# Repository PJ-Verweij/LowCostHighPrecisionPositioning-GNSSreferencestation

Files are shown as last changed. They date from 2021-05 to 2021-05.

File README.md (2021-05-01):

# LowCostHighPrecisionPositioning - GNSSreferencestation

This Github repository contains the manual and production files for the GNSSreferencestation. This design is an improved version of BASE2: [ROVER2 and BASE2 githubpage](https://github.com/PJ-Verweij/LowCostHighPrecisionPositioning---BASE2-ROVER2) <br/><br/>

-In the Documentation folder a manual can be found which explains how to assemble the GNSS reference station <br/>
-In the production files folder the STL file of the antenna top can be found to print the antenna top.
Furthermore, there are Gerber files of the PCB. It is handy to notice that some production facilities also accept the Kicad files. <br/><br/>

-The CAD_model folder can be downloaded an opened with Solidworks (2019 or higher) <br/>
-The PCB folder can be downloaded and opened with KiCad <br/><br/>

-In the Software manuals folder some scripts and instructions are given to demonstrate the functionality of the circuits on the PCB.
For the full Raspberry PI software image and configuration I refer to Andreas Krietemeyer.

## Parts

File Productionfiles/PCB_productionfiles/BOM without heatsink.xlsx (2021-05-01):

Designator | Value | Clarification | Manufacturer | Manufacturer Part Number | Type | Quantity
BT1-BT16 | Battery_Cell | 20700 battery clips | Keystone | 246TR | Thru-Hole | 16
C1-C7 | 10µ | 10µF capacitor | AVX | 12105C106MAT4A | SMD | 7
C8, C9, C14 | 1µ | 1µF capacitor | AVX | 08055C105K4T4A | SMD | 3
C10 | 2.2µ | 2.2µF capacitor | AVX | 12105C225KAZ2A | SMD | 1
C11, C13 | 0.1µ | 0.1µF capacitor | AVX | 08055C104KAT4A | SMD | 2
C12 | 22p | 22pF capacitor | AVX | 06035C220JAT2A | SMD | 1
C15, C18-C20 | 0.1µF | SMD 0.1µF capacitor | AVX | 06035L104K4T4A | SMD | 4
C16 | 10µF | 10µF | AVX | 06033D106MAT2A | SMD | 1
C17 | 22µF | 22µF | AVX | 12063D226KAT2A | SMD | 1
C21 | 22pF | SMD 22pF capacitor | AVX | 06035A220JAT4A | SMD | 1
C22, C25 | 33pF | SMD 33pF capacitor | AVX | 0603YA330F4T2A | SMD | 2
C23 | 100µF | SMD 100µF polarized capacitor | AVX | TCJD107M025R0070E | SMD | 1
C24 | 10pF | SMD 10pF capacitor | AVX | 06035C100K4T4A | SMD | 1
D4, D5 | SMA6T28CAY | ESD protection schottkey diode | STMicroelectronics | SMA6T30CAY | SMD | 2
D1-D3, D6, D10, D11 | LED | SMD RED 2mA LED | Kingbright | APHD1608LSURCK | SMD | 6
D8 | BAT54C | Schottkey diode | Vishay | BAT54C | SMD | 1
D9 | SMA6T30CAY | ESD protection schottkey diode | STMicroelectronics | SMA6T30CAY | SMD | 1
D12, D13 | MBRA210LT3G | Schottkey diode | ON Semiconductor | MBRA210LT3G | SMD | 2
F1 | 8A | 20x5 Fuse holder | Schurter | 318201 | Thru-Hole | 1
F2-F9 | 2A | 20x5 Fuse holder | Schurter | 318201 | Thru-Hole | 8
IC1 | BQ24650RVAT | MPPT solar power converter IC | Texas Instruments | BQ24650RVAT | SMD | 1
IC2 | SC16IS752IPW,128 | I2C to UART IC | NXP | SC16IS752IPW,128 | SMD | 1
J1, J2 | Conn_01x05_Female |  | TE Connectivity / AMP | 4DB-P107-05 | Thru-Hole | 2
J3, J7 | Female Header 1x8 pin |  | Sullins Connector Solutions | PPPC081LFBN-RC | Thru-Hole | 2
J4, J10, J12 | Female Header 1x6 pin |  | Sullins Connector Solutions | PPPC061LFBN-RC | Thru-Hole | 3
J5 | RPi_header |  | Sullins Connector Solutions | PPPC202LFBN-RC | Thru-Hole | 1
J6 | Female Header 1x10 pin |  | Sullins Connector Solutions | PPPC101LFBN-RC | Thru-Hole | 1
J8, J9 | Female Header 1x10 pin (2mm spacing) |  | Sullins Connector Solutions | S5751-10-ND | Thru-Hole | 2
J11 | Conn_Coaxial | Vertical SMA connector | Linx Technologies | CONSMA001-C-G | Thru-Hole | 1
J13 | Conn_Coaxial | U.FL connector | Hirose Connector | U.FL-R-SMT(10) | SMD | 1
JP1 | Jumper_NC_Dual | 1x3 pin header | Amphenol FCI | 10129378-903001BLF | Thru-Hole | 1
L1 | 15µH | 15µH inductor | Coilcraft | SER1390-153MLB | SMD | 1
L2 | MSD1514-252MED | 2.5 µH Coupled-inductor | Coilcraft | MSD1514-252MED | SMD | 1
L3 | 2.2µH | 2.2µH inductor | Coilcraft | D03316P-222 | SMD | 1
L4 | 2.2µH | 2.2µH Coupled-inductor | Bourns | SRF0703-2R2M | SMD | 1
PS1 | LTC3426 | Switching Voltage Regulator | Linear Technology | LTC3426ES6#TRMPBF | SMD | 1
Q3, Q4 | CSD16406Q3 | N-Channel mosfet | Texas Instruments | CSD16406Q3 | SMD | 2
Q5 | DTC143Z | Bipolar transistor pre biased | Nexperia | NHDTC143ZTR | SMD | 1
R1 | 560 | SMD 560Ohm resistor | Vishay | CRCW0603560RFKEAC | SMD | 1
R2-R5 | 1.5K | SMD 1.5K resistor | Vishay | CRCW06031K50FKEAC | SMD | 4
R6 | 0.008 | SMD 0.008Ω current sense resistor | Vishay/Dale | WSLP25128L000FEA | SMD | 1
R7 | 10 | SMD 10Ω resistor | Vishay / Dale | RCS120610R0FKEA | SMD | 1
R8 | 324K | SMD 324K resistor | Vishay / Dale | CRCW0603324KFKEA | SMD | 1
R9 | 511K | SMD 511K resistor | Vishay / Dale | CRCW0603511KFKEA | SMD | 1
R10 | 2 | SMD 2Ω resistor | Vishay / Dale | CRCW08052R00FKEAC | SMD | 1
R11 | 36K | SMD 36K resistor | Vishay / Dale | CRCW060336K0FKEAC | SMD | 1
R12 | 340K | SMD 340K resistor | Vishay/Dale | CRCW0603340KFKEAC | SMD | 1
R13 | 348K | SMD 348K resistor | Vishay/Dale | CRCW0603348KFKEA | SMD | 1
R14, R16 | 820 | SMD 820Ω resistor | Vishay / Dale | CRCW0603820RFKEA | SMD | 2
R15 | 3.48K | SMD 3.48K resistor | Vishay / Dale | CRCW06033K48FKEA | SMD | 1
R17 | 14.7K | SMD 14.7K resistor | Vishay / Dale | CRCW060314K7FKEB | SMD | 1
R18 | 330 | SMD 330ohm resistor | Vishay | CRCW0603330RFKEA | SMD | 1
R19 | 2.2K | SMD 2.2K resistor | Vishay | CRCW06032K20JNEA | SMD | 1
R20, R21 | 5.1M | SMD 5.1M resistor | Vishay | CRCW06035M10FKEA | SMD | 2
R22 | 95.3K | SMD 95.3K resistor | Vishay | CRCW060395K3FKEA | SMD | 1
R23 | 1M | SMD 1M resistor | Vishay | CRCW06031M00FKEB | SMD | 1
R24 | 30.9K | SMD 30.9K resistor | Vishay | CRCW060330K9FKEA | SMD | 1
R25 | 10K | SMD 10K resistor | Vishay | CRCW060310K0FKEAC | SMD | 1
R26, R27 | 1K | SMD 1K resistor | Vishay | CRCW06031K00FKEAC | SMD | 2
TH1 | 10K | 10K NTC Thermistor | Semitec | 103AT-2 | Thru-Hole | 1
U1 | BQ29700 | Battery protection circuit | Texas Instruments | BQ29700DSER | SMD | 1
U2 | LM35-LP | Temperature sensor | Texas Instruments | LM35DZ | Thru-Hole | 1
U3 | MCP3008 | MCP3008 analog-digital converter | Microchip | MCP3008T-I/SL | SMD | 1
Y1 | 14.7456M | 14.7456Mhz crystal | IQD | LFXTAL003224 | Thru-Hole | 1

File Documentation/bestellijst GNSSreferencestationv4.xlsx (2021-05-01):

Component | Single piece price | Package | Amount 1 unit | 1 Unit | Amount 10 units | 10 units price | Amount 20 units | 20 units price | Discount percentage for 20 units
Enclosure FLT 350250150 GR | €22.32 | 1 | 1 | €22.3 | 10 | €223.2 | 20 | €433.01 | 3% | https://www.reichelt.nl/nl/nl/wandgehaeuse-ip65-250-x-350-x-150-mm-grau-flt-350250150-gr-p262988.html?nbc=1
GSM antenna DELOCK 89618 | €7.52 | 1 | 1 | €7.5 | 10 | €75.2 | 20 | €150.40 | 0% | https://www.reichelt.de/gb/en/lte-antenna-sma-plug-omnidirectional-delock-89618-p259573.html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
Raspberry Zero | €12.25 | 1 | 1 | €12.2 | 10 | €122.5 | 20 | €245.00 | 0% | https://www.reichelt.nl/nl/nl/raspberry-pi-zero-v-1-3-1-ghz-512-mb-ram-rasp-pi-zero-p256439.html?nbc=1
 |  |  | Shop sum: | €42.1 |  | €420.9 |  | €828.41
Cell 21700 Samsung INR21700-50E | €6.45 | 1 | 8 | €63.7 | 80 | €461.6 | 160 | €923.20 | 27.51256281% | https://www.tme.eu/nl/details/accu-inr21700-50e/accus/samsung-sdi/inr21700-50e/
NAC3MPX-TOP NEUTRIK | €3.82 | 1 | 1 | €3.8 | 10 | €33.9 | 20 | €67.8 | 11.2565445% | https://www.tme.eu/nl/details/ntr-nac3mpx-top/overige-ac-connectoren/neutrik/nac3mpx-top/
NAC3FX-W-TOP NEURTIK | €9.06 | 1 | 1 | €9.1 | 10 | €81.5 | 20 | €145.0 | 19.97792494% | https://www.tme.eu/nl/details/ntr-nac3fx-w-top/overige-ac-connectoren/neutrik/nac3fx-w-top/
SCNAC-MPX NEUTRIK | €1.26 | 1 | 1 | €1.3 | 10 | €11.3 | 20 | €20.2 | 19.84126984% | https://www.tme.eu/nl/details/ntr-scnac-mpx/overige-connectors-van-neutrik/neutrik/scnac-mpx/
spacer m2.5x10mm | €0.13 | 1 | 7 | €0.9 | 70 | €9.2 | 140 | €15.1 | 17.41787624% | https://www.tme.eu/nl/details/tfm-m2.5x10_dr2112/metalen-afstandhouders/dremec/2112x10/
m2.5 nut (steel) | €0.88 | 100 | 7 | €0.1 | 70 | €0.6 | 140 | €1.23 | 0% | https://www.tme.eu/nl/details/b2.5_bn109/moeren/bossard/1088254/
m2.5x6 philipshead bolt (Steel) | €2.30 | 100 | 7 | €0.2 | 70 | €1.6 | 140 | €3.22 | 0% | https://www.tme.eu/nl/details/b2.5x6_bn1435/bouten/bossard/1219561/
spacer m4x10mm | €0.13 | 1 | 7 | €0.9 | 70 | €9.23 | 140 | €15.2 | 17.81652767% | https://www.tme.eu/nl/details/tfm-m4x10_dr226/metalen-afstandhouders/dremec/226x10/
m4 nut (steel) | €1.04 | 100 | 7 | €0.1 | 70 | €0.7 | 140 | €1.46 | 0% | https://www.tme.eu/nl/details/b4_bn115/moeren/bossard/1089013/
m4x6 philipshead bolt (Steel) | €2.02 | 100 | 7 | €0.1 | 70 | €1.4 | 140 | €2.83 | 0% | https://www.tme.eu/nl/details/b4x6_bn1435/bouten/bossard/1219928/
m4x25 sockethead bolt (RVS) | €2.87 | 100 | 2 | €0.1 | 20 | €0.6 | 40 | €1.15 | 0% | https://www.tme.eu/nl/details/m4x25_d912-a2/bouten/kraftberg/
m4 nut (RVS) | €0.72 | 100 | 2 | €0.0144 | 20 | €0.1 | 40 | €0.29 | 0% | https://www.tme.eu/nl/details/m4_d934-a2/moeren/kraftberg/
m8x40 sockethead bolt (RVS) | €12.74 | 100 | 1 | €0.1 | 10 | €1.3 | 20 | €2.55 | 0% | https://www.tme.eu/nl/details/m8x40_d912-a2/bouten/kraftberg/
m8 nut (RVS) | €3.12 | 100 | 1 | €0.03 | 10 | €0.3 | 20 | €0.62 | 0% | https://www.tme.eu/nl/details/m8_d934-a2/moeren/kraftberg/
m3x8 sockethead bolt (Steel) | €3.10 | 100 | 2 | €0.06 | 20 | €0.6 | 40 | €1.24 | 0% | https://www.tme.eu/nl/details/b3x8_bn17/bouten/bossard/3186761/
m3 nut (Steel) | €0.95 | 100 | 2 | €0.02 | 20 | €0.2 | 40 | €0.38 | 0% | https://www.tme.eu/nl/details/b3_bn115/moeren/bossard/1088998/
16GB SD card Sandisk | €5.60 | 1 | 1 | €5.6 | 10 | €50.1 | 20 | €88.6 | 20.89285714% | https://www.tme.eu/nl/details/sdsquns-016g-gn3mn/geheugenkaarten/sandisk/
Stego | €11.16 | 1 | 1 | €11.2 | 10 | €99.60 | 20 | €176.60 | 20.8781362% | https://www.tme.eu/nl/details/08410.0-00/cabinets-accessories/stego/
PG9 cable gland | €1.80 | 5 | 2 | €0.7 | 20 | €7.20 | 40 | €14.40 | 0% | https://www.tme.eu/nl/details/pg9_bk/wartels/aks-zielonka/220215/
2x20pin header for raspberry | €3.29 | 10 | 1 | €0.3 | 10 | €3.29 | 20 | €6.58 | 0% | https://www.tme.eu/nl/details/zl202-40g/lijsten-en-pin-achtige-stopcontacten/connfly/ds1021-2-20sf11/
1x20pin header for GNSS receiver | €1.96 | 10 | 2 | €0.4 | 20 | €3.92 | 50 | €7.77 | 0.8928571429% | https://www.tme.eu/nl/details/zl201-20g/lijsten-en-pin-achtige-stopcontacten/connfly/ds1021-1-20sf11/
Fuses 2A | €1.17 | 10 | 8 | €0.9 | 80 | €8.2 | 160 | €12.78 | 31.70940171% | https://www.tme.eu/nl/details/zcs-2a/zekeringen-5x20mm-snele/eska/520-520/
Fuses 8A | €1.04 | 10 | 1 | €0.1 | 10 | €1.0 | 20 | €2.08 | 0% | https://www.tme.eu/nl/details/zks-8a_125v/zekeringen-5x20mm-snele/eska/520-626/
M4 cable lug | €0.70 | 10 | 6 | €0.4 | 60 | €3.2 | 120 | €6.43 | 22.99956903% | https://www.tme.eu/nl/details/tmev1.25-4m/geisoleerde-connectoren/nichifu/tmev-1-25-4m/
Cable black 18AWG | €21.27 | 30 | 1 | €0.7 | 10 | €7.1 | 20 | €14.18 | 0% | https://www.tme.eu/nl/details/1555-bk005/enkeladerige-draden-koord/alpha-wire/1555-bk005/
Cable red 18AWG | €21.27 | 30 | 1 | €0.7 | 10 | €7.1 | 20 | €14.18 | 0% | https://www.tme.eu/nl/details/1555-rd005/enkeladerige-draden-koord/alpha-wire/1555-rd005/
Cable 2 wires 17AWG | €3.85 | 5 | 3 | €2.3 | 30 | €20.7 | 60 | €36.60 | 20.77922078% | https://www.tme.eu/nl/details/ol-eb-2x1/meeraderige-draden-niet-afgeschermd/lapp/0012440/
Jumper | €0.66 | 20 | 1 | €0.03 | 10 | €0.3 | 20 | €0.66 | 0% | https://www.tme.eu/nl/details/jumper-r-z/lijsten-en-pin-achtige-stopcontacten/ninigi/
 |  |  | Shop sum: | €99.6 |  | €787.5 |  | €1510.29
ON/OFF switch | €4.91 | 1 | 1 | €4.91 | 10 | €49.10 | 20 | €98.20 | 0% | https://nl.rs-online.com/web/p/push-button-switches/7064073/?searchHistory=%7B%22enabled%22%3Atrue%7D
Panel Mount Indicator, 8mm | €4.12 | 1 | 1 | €4.12 | 10 | €37.70 | 20 | €75.40 | 8.495145631% | https://nl.rs-online.com/web/p/indicators/1950260/
 |  |  | Shop sum: | €9.03 |  | €86.80 |  | €173.60
SBR10U40CT | €1.19 | 1 | 1 | €1.19 | 10 | €9.74 | 20 | €19.48 | 18.1512605% | https://nl.mouser.com/ProductDetail/Diodes-Incorporated/SBR10U40CT?qs=7r0W2zb%2F88xvLBVZUVD9Zw%3D%3D
513002B02500G | €0.85 | 1 | 2 | €1.71 | 20 | €16.30 | 40 | €31.64 | 7.485380117% | https://nl.mouser.com/ProductDetail/Aavid/513002B02500G
CSD18537NKCS | €1.15 | 1 | 2 | €2.30 | 20 | €19.14 | 40 | €38.28 | 16.7826087% | https://nl.mouser.com/ProductDetail/Texas-Instruments/CSD18537NKCS
 |  |  | Shop sum: | €5.20 |  | €45.18 |  | €89.40
PCB | €778.70 | 1 | 1 | €778.7 | 10 | €1938.6 | 20 | €2889.80 | 81.44471555% | https://www.eurocircuits.com/
Aluminium 120mmx2mm groundplane | €11.90 | 1 | 1 | €11.9 | 10 | €30.0 | 20 | €43.40 | 81.76470588% | https://www.metalpoint.nl/vlak-plaatwerk/schijf.html
Ardusimple | €211.00 | 1 | 1 | €211.0 | 10 | €2110.0 | 20 | €4220.00 | 0% | https://www.ardusimple.com/product/simplertk2b-basic-starter-kit-ip65/
SPP040201200 (20watt, polycristaline -> panel used in design) | €34.95 | 1 | 1 | €34.95 | 10 | €349.50 | 20 | €699.00 | 0% | https://www.druppellader.com/victron-bluesolar-20wp-poly.html
SPM040201200 (20Watt, monocrystalline) | €37.51 | 1 | 1 | €37.5 | 10 | €375.1 | 20 | €750.20 | 0% | https://www.bluepowershop.nl/solar/solar-panelen/victron-solar-panel-20w-12v-mono.html
SPP040301200 (30Watt, polycrystalline) | €39.95 | 1 | 1 | €40.0 | 10 | €399.5 | 20 | €799.00 | 0% | https://www.acculaders.nl/victron-bluesolar-30wp-poly.html
SPM040301200 (30Watt, monocrystalline) | €43.56 | 1 | 1 | €43.6 | 10 | €435.6 | 20 | €871.20 | 0% | https://www.bluepowershop.nl/solar/solar-panelen/victron-solar-panel-30w-12v-mono.html
SPM040401200 (40Watt, monocrystalline) | €55.66 | 1 | 1 | €55.7 | 10 | €556.6 | 20 | €1113.20 | 0% | https://www.bluepowershop.nl/solar/victron-solar-panel-40w-12v-mono.html
SPM040551200 (50Watt, monocrystalline) | €72.60 | 1 | 1 | €72.6 | 10 | €726.0 | 20 | €1452.00 | 0% | https://www.bluepowershop.nl/solar/solar-panelen/victron-solar-panel-55w-12v-mono.html
3D printed antenna platform (PETG) |  |  |  |  |  |  |  |  |  | Github page
Aluminium pole 25x2x1000 | €6.90 | 1 | 1 | €6.9 | 10 | €69.0 | 20 | €138.00 | 0% | https://www.aluminiumopmaat.nl/aluminium-buizen/aluminium-buis-rond.html
Saddle clamps for pole | €1.94 | 1 | 2 | €3.9 | 20 | €38.8 | 40 | €77.60 | 0% | https://nl.rs-online.com/web/p/cable-clips-clamps/0606018/
 |  |  | Total order sum: | €1192.5 |  | €5768.5 |  | €10453.90
 |  |  | Unit price: | €1192.5 |  | €576.9 |  | €522.69 | (without pole and clamps, with 20watt polycristalline panel)
Normal text = Needed components
Orange text = optional comonents

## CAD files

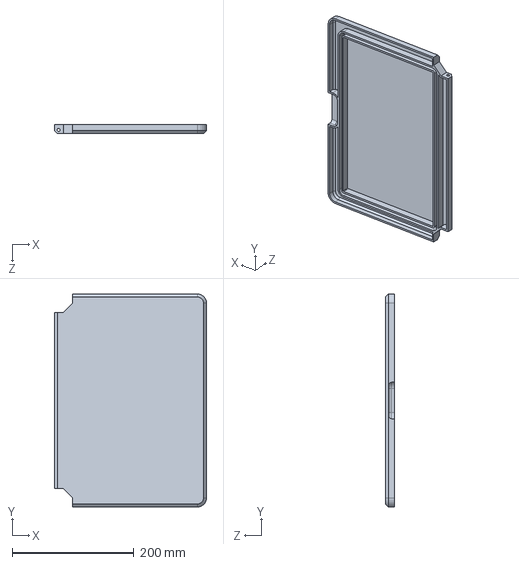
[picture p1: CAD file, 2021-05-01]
CAD_model/Main_unit/Enclosure-components/Main-Unit.Enclosure.Door.SLDPRT
250.0 x 350.0 x 15.0 mm

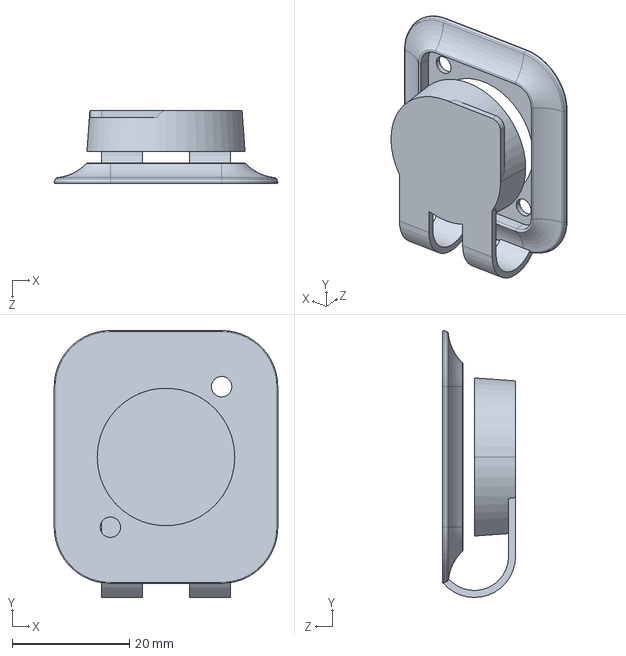
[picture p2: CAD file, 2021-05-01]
CAD_model/Main_unit/Enclosure-components/Neutric_Connector/Main-Unit.Neutric_Connector.3-d-scnac-mpx.SLDPRT
38.2 x 45.6 x 12.5 mm

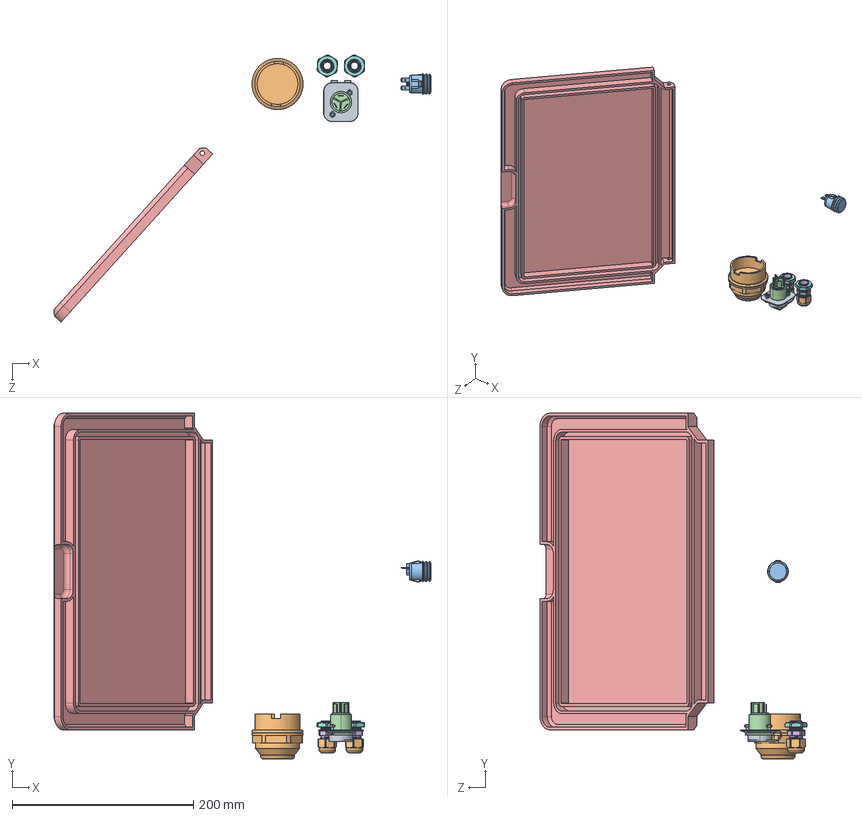
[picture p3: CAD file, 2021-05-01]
CAD_model/Main_unit/Main-Unit.Enclosure.Assembly.SLDASM
416.4 x 382.0 x 295.1 mm
Main-Unit.Enclosure.Door
Cable Gland PG7-PG19 Body x 2
Cable Gland PG7-PG19 Washer x 2
Cable Gland PG7-PG19 Lock Nut x 2
Cable Gland PG7-PG19 Sleeve x 2
Cable Gland PG7-PG19 Gland Nut x 2
Main-Unit.Neutric_Connector.NAC3MPX-TOP
Main-Unit.Button_kfb2ana1bbb
Main-Unit.Drainelement_08410.0-00-STEGO-base
Main-Unit.Neutric_Connector.3-d-scnac-mpx
countersunk flat head cross recess screw_din x 2
hex nut style 1 gradeab_din x 2

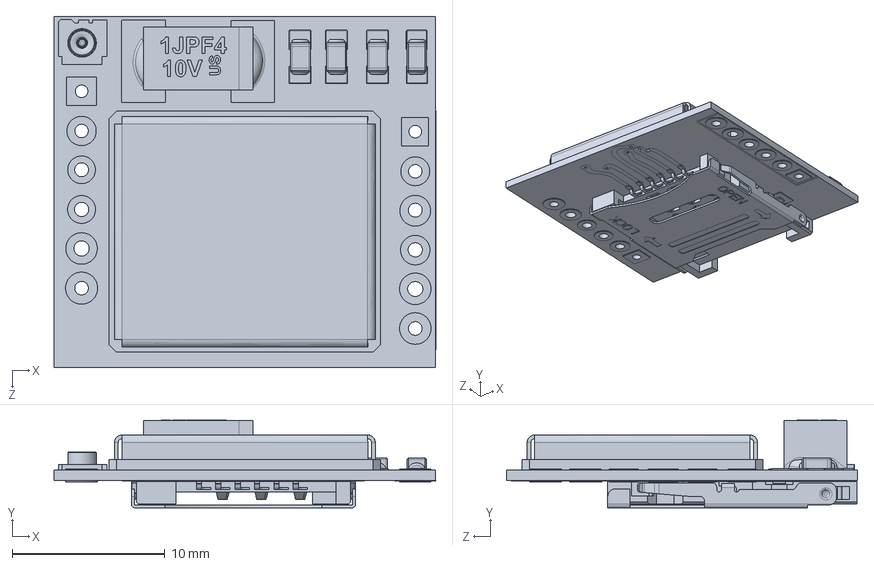
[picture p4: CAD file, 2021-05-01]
CAD_model/Main_unit/PCB-components/Main-Unit.SIM800_GPRSmodem.SLDPRT
25.0 x 5.77 x 23.0 mm

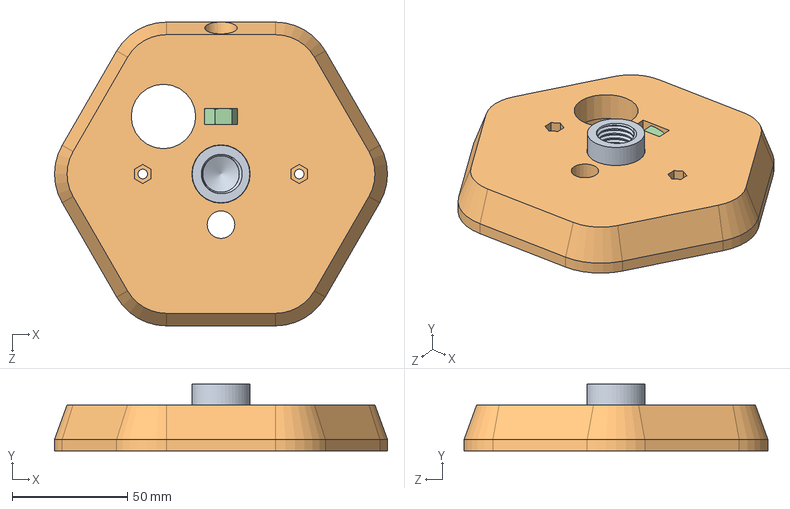
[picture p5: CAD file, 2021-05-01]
CAD_model/Antenna/antennatop58-11uncadapter.SLDASM
144.7 x 29.0 x 132.0 mm
thread adapter antenna top
antenna top
socket head cap screw_am
hex nut style 2_am

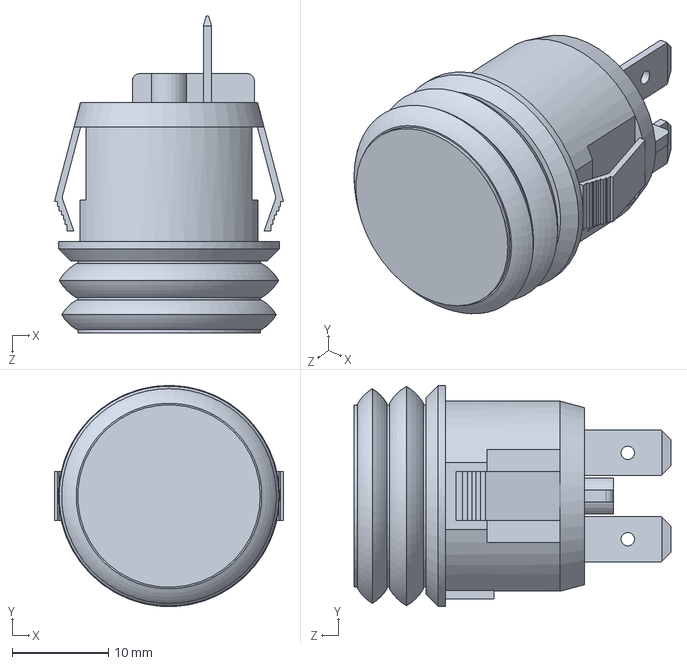
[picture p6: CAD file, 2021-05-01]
CAD_model/Main_unit/Enclosure-components/Main-Unit.Button_kfb2ana1bbb.SLDPRT
23.8 x 23.0 x 33.0 mm

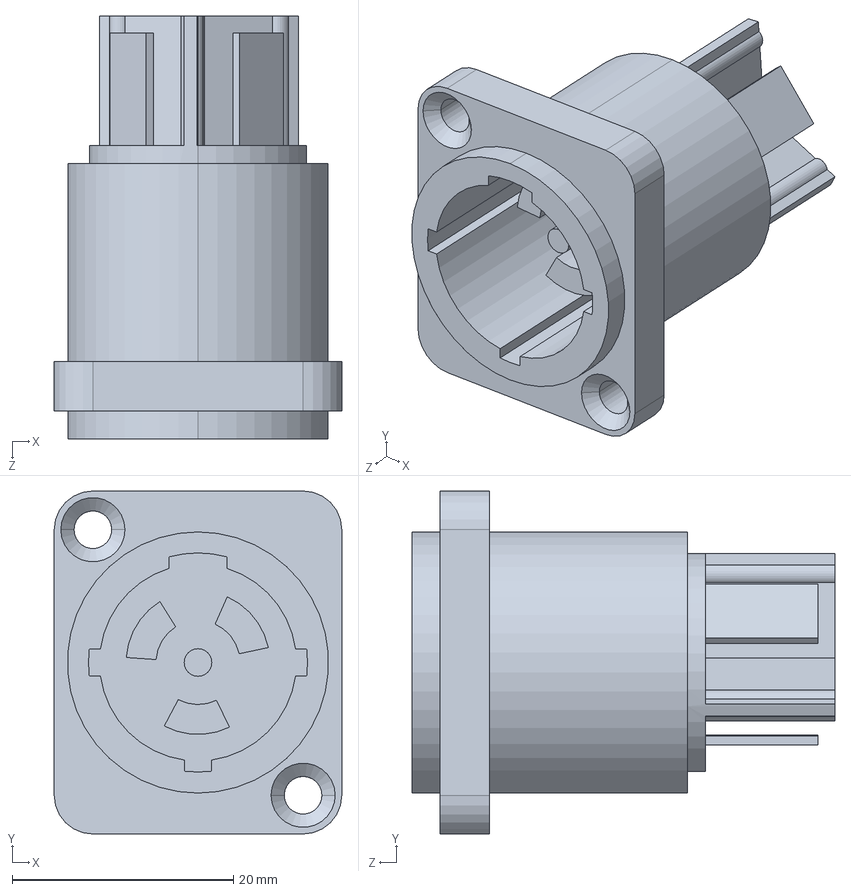
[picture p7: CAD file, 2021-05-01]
CAD_model/Main_unit/Enclosure-components/Neutric_Connector/Main-Unit.Neutric_Connector.NAC3MPX-TOP.SLDPRT
26.0 x 31.0 x 38.2 mm

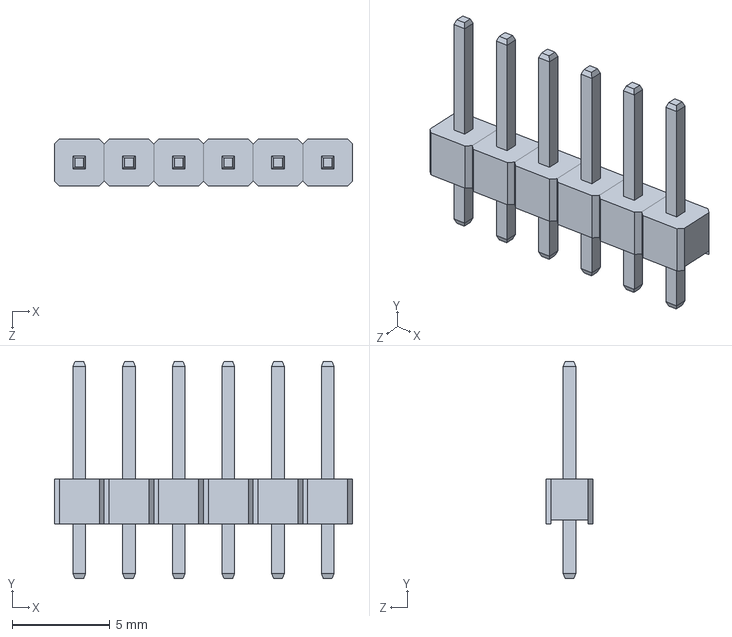
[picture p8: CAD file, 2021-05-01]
CAD_model/Main_unit/PCB-components/Pinheaders/Main-Unit.6x_Pinheader_2.54mm.Assembly.SLDASM
15.2 x 11.1 x 2.40 mm
Main-Unit.Male_Pin_2.54_mm x 6

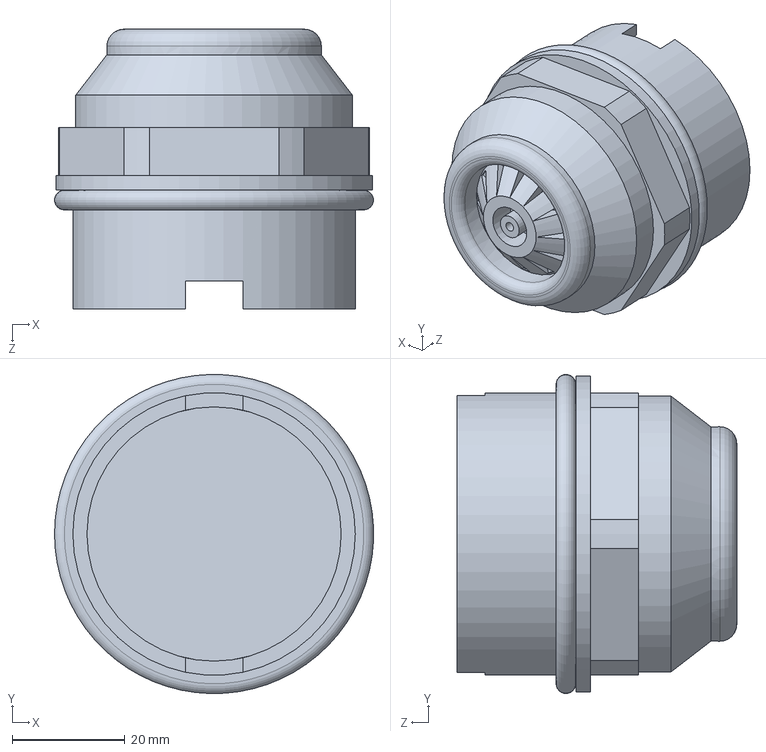
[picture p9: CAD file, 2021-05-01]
CAD_model/Main_unit/Enclosure-components/Main-Unit.Drainelement_08410.0-00-STEGO-base.SLDPRT
56.5 x 56.5 x 49.5 mm

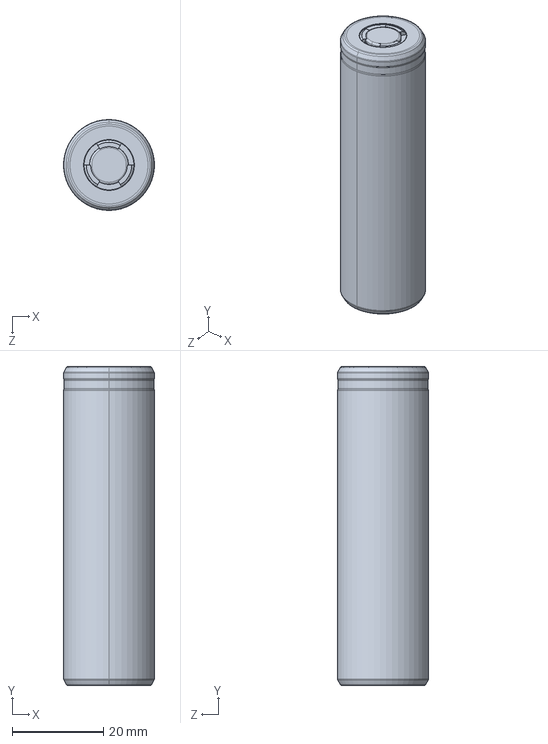
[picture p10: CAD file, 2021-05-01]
CAD_model/Main_unit/PCB-components/Main-Unit.21700_Battery.SLDPRT
19.9 x 70.0 x 20.0 mm

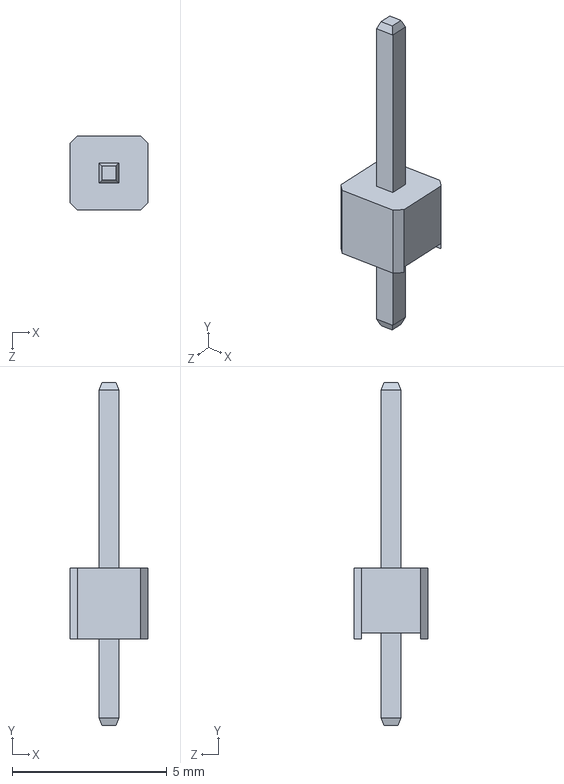
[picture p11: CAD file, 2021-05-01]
CAD_model/Main_unit/PCB-components/Pinheaders/Main-Unit.Male_Pin_2.54_mm.SLDPRT
2.54 x 11.1 x 2.40 mm

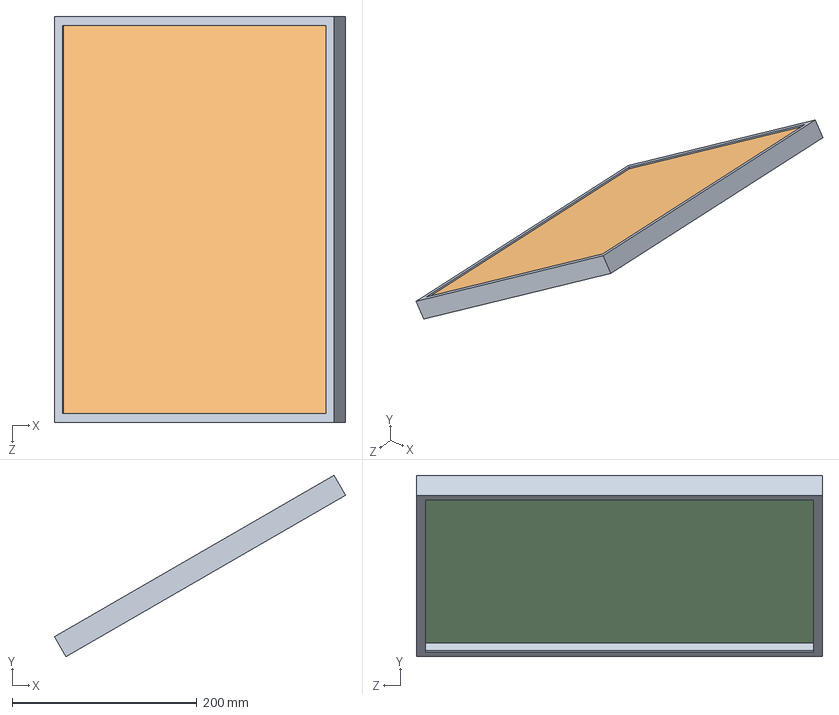
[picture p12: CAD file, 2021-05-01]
CAD_model/Solarpanel/GNSSreferencestation.Solarpanel.Assembly.SLDASM
315.6 x 196.7 x 440.0 mm
Solarpanel.sides
Solarpanel.glass
Solarpanel.cells
Solarpanel.backplate

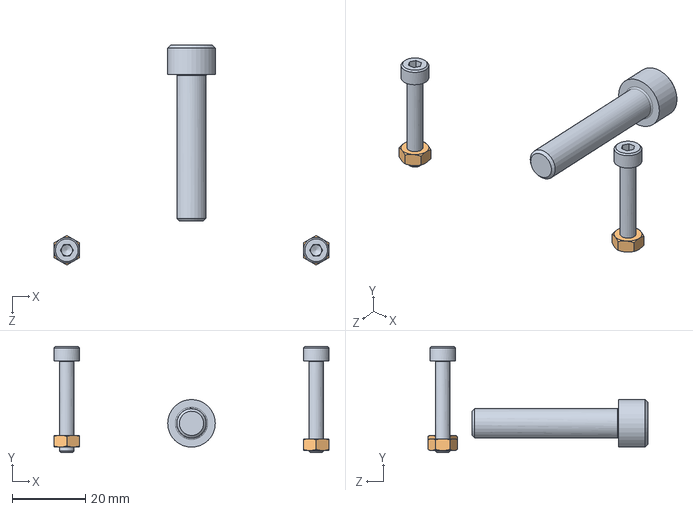
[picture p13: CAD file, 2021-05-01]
CAD_model/Antenna/GNSSreferencestation.Antenna.Assembly.SLDASM
75.0 x 29.0 x 60.0 mm
socket head cap screw_am x 3
hex nut style 1_am x 2

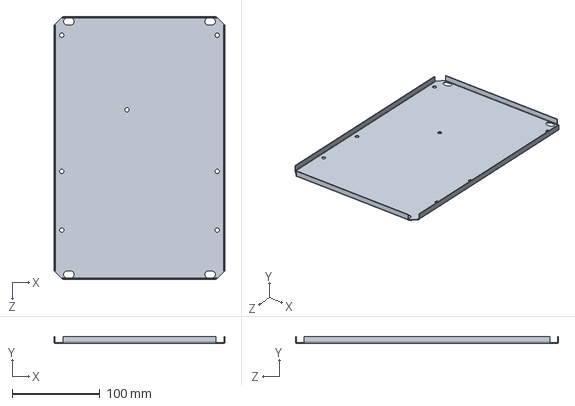
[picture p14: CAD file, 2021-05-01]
CAD_model/Main_unit/Enclosure-components/Main-Unit.Enclosure.Backplate.SLDPRT
195.0 x 8.00 x 300.0 mm

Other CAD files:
CAD_model/Main_unit/PCB-components/Pinheaders/Main-Unit.10x_Pinheader_2mm.sldprt
CAD_model/Main_unit/PCB-components/Main-Unit.Example_Xbee.Assembly.sldasm
CAD_model/Solarpanel/Solarpanel.Victron_20watt.Assembly.SLDASM
CAD_model/Main_unit/PCB-components/Main-Unit.SIM800_GPRSmodem_Withheader.Assembly.SLDASM
CAD_model/Antenna/Antenna.Antennatop.Assembly.SLDASM
CAD_model/Antenna/Antenna.Pole-1000mmx25mm.SLDPRT
CAD_model/Antenna/Antennatop.Base.SLDPRT
CAD_model/Antenna/Antennatop.Cellular-Antenna.SLDPRT
CAD_model/Antenna/Antennatop.Groundplane.SLDPRT
CAD_model/Antenna/thread adapter antenna top.SLDPRT
CAD_model/Antenna/thread adapter.SLDDRW
CAD_model/Main_unit/Cable-gland-pg7-pg19/Cable Gland PG7-PG19 Body.SLDPRT
CAD_model/Main_unit/Cable-gland-pg7-pg19/Cable Gland PG7-PG19 Gland Nut.SLDPRT
CAD_model/Main_unit/Cable-gland-pg7-pg19/Cable Gland PG7-PG19 Lock Nut.SLDPRT
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

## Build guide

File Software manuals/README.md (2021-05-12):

In the subfolders of this directory you can find software manuals to get the separate hardware components to work on a fresh install of raspberry PI OS

However, there is also a pre-configured image for the GNSSreferencestation (still to be uploaded)
This image can be written to the SD card using the DD command or the graphical <a href="https://github.com/thefanclub/dd-utility">DD utility</a>. (available for Mac OS and Linux)

In the image you still have to edit file [fixme] to fill the right [mountpoint] and [telecomprovider data]

Also remember to upload the base station configuration to the GNSS receiver using the Ublox U-center software.

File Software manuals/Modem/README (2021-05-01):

How to get SIM800 to work with Raspberry PI

1. Make internet connection for installation
Connect Raspberry to Internet by Wifi or Ethernet

2. Enable serial port
In Raspberry Pi configuration -> interfaces
- Enable Serial Port
- Disable Serial Console

3. Turn off pincode
This step only has to be done if the SIM card still has an active pincode
Turning of the pincode is needed while the AT+CPIN command reply’s with OK to soon. This will cause the chat script to go on before the modem is ready.

Install minicom
Terminal commands:
sudo apt-get update
sudo apt-get install minicom

Connect to modem
Terminal command:
sudo minicom -D /dev/ttyS0 -b 115200

Turn off pincode in minicom
minicom command:
ATZ should return OK
AT+CPIN? should return +CPIN: SIM PIN indicating SIM PIN is needed
AT+CPIN="xxxx" replace xxxx by your PINCODE. should return OK. you have access to the SIM
AT+CLCK="SC",0,"xxxx" replace xxxx by your PINCODE. to disable the pin code

4. Install ppp, for serial data connections
Terminal commands:
Sudo apt-get update
Sudo apt-get install ppp

5. Place configuration and chatscript
Create or paste the chatscript in folder /etc/ppp (GPRS.chat, can be found in this directory)
Create or paste the ppp configuration file in /etc/ppp/peers (GPRSconfig, can be found in this directory, you might need to alter the APN username and password in this file.)

6. Start the connection
Terminal command:
Sudo pon GPRSconfig
(Connection can be turned off again with “Sudo off GPRSconfig”)

7. Check the connection
Terminal command:
Ifconfig
This will now show a new connection: ppp0
The proces of setting up the connection and potential errors can be tracked with te terminal command:
cat /var/log/syslog | grep pppd

8. Make the ppp0 connection the default route
Terminal command:
Sudo route add default dev ppp0

9. Check the connection
Load a webpage in the browser or ping an webadres with terminal command:
Ping google.com

If you have a browser, speedtest can be run at:
TestMy.net
Upload will be between 30 and 45kbps
Download will be between 80 and 100kbps

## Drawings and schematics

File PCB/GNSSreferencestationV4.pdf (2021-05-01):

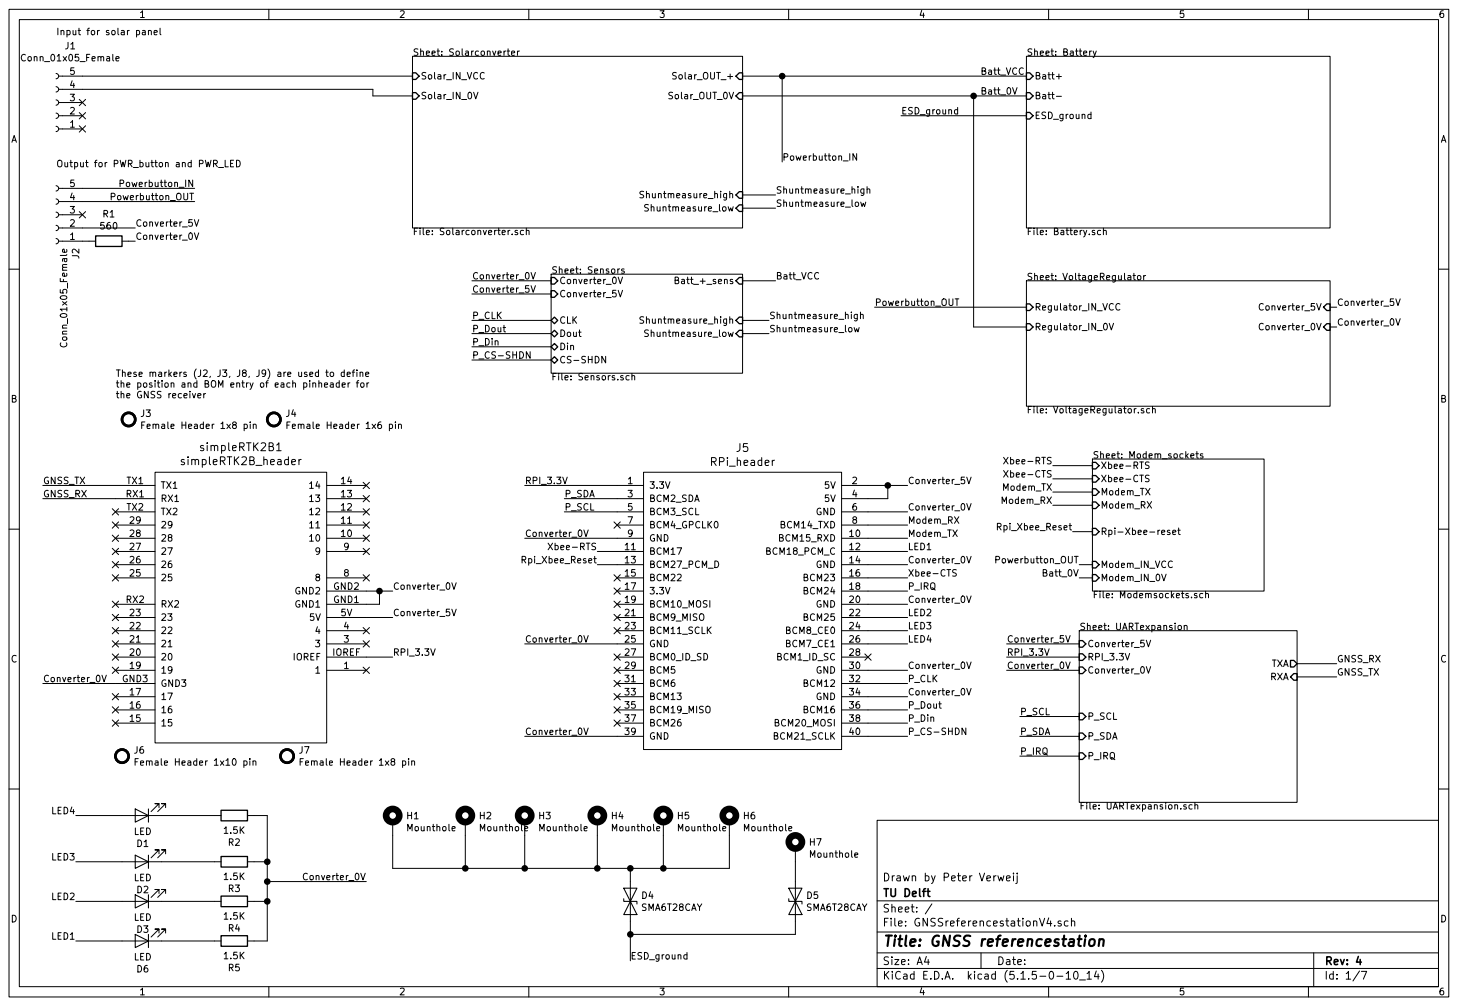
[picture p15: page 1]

Input for solar panel

Sheet: Battery
File: Battery.sch Batt+ Batt- ESD_ground
Batt_0V Converter_0V Converter_0V Converter_0V

the GNSS receiver Output for PWR_button and PWR_LED

Sheet: Sensors File: Sensors.sch Converter_0V Converter_5V CLK Dout Din CS-SHDN

These markers (J2, J3, J8, J9) are used to define
the position and BOM entry of each pinheader for

Sheet: Modem_sockets File: Modemsockets.sch Xbee-RTS

Xbee-CTS Modem_TX Modem_RX Rpi-Xbee-reset Modem_IN_VCC Modem_IN_0V

File: GNSSreferencestationV4.sch Sheet: / TU Delft Drawn by Peter Verweij

Id: 1/7 Title: GNSS referencestation

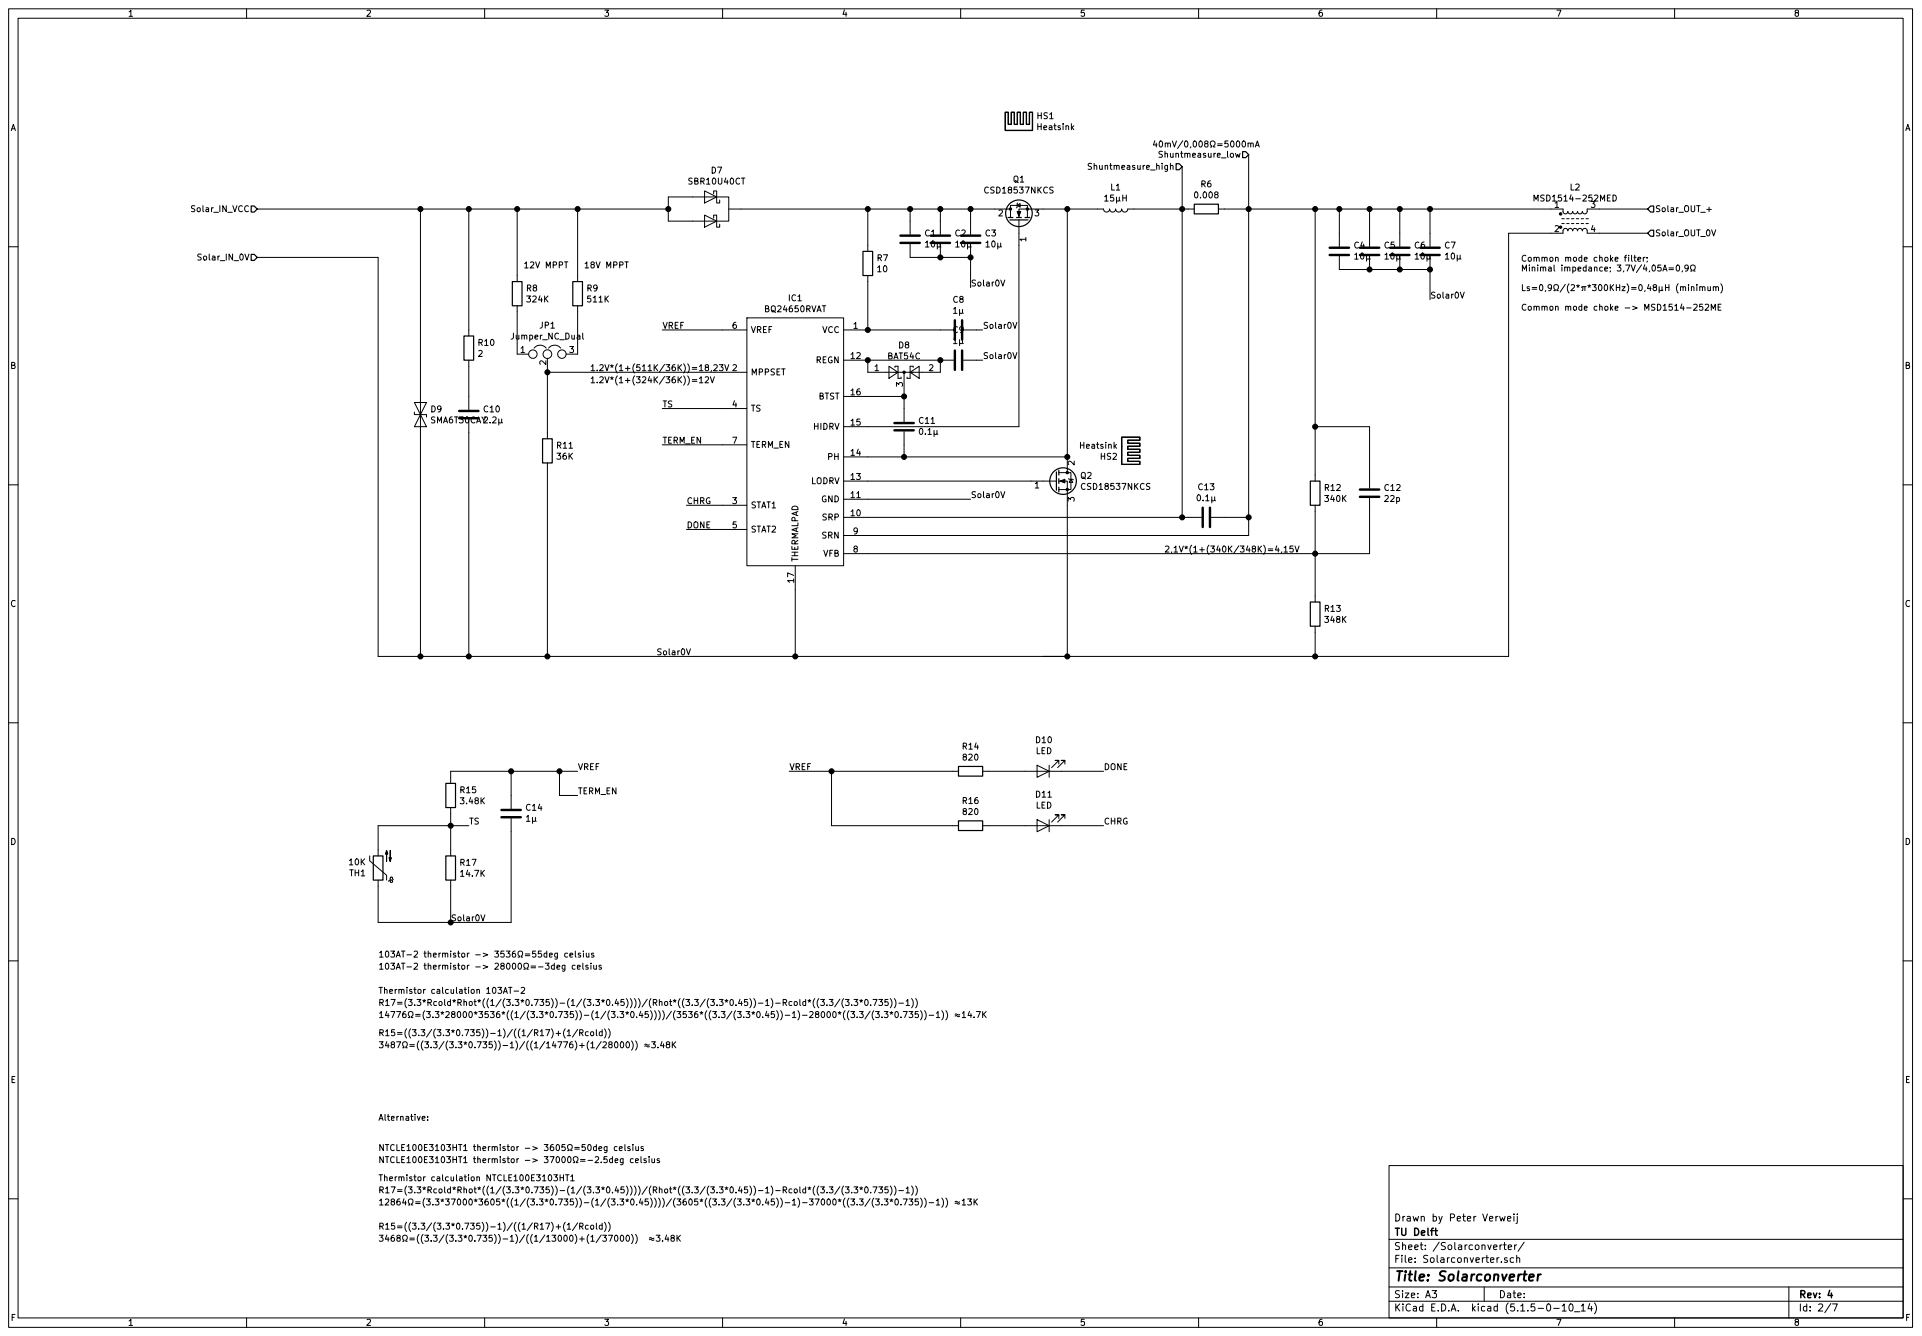
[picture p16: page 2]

Common mode choke filter; Minimal impedance; 3,7V/4,05A=0,9

Ls=0,9/(2**300KHz)=0,48µH (minimum) Common mode choke -> MSD1514-252ME

NTCLE100E3103HT1 thermistor -> 3605=50deg celsius
NTCLE100E3103HT1 thermistor -> 37000=-2.5deg celsius
Thermistor calculation NTCLE100E3103HT1
R17=(3.3*Rcold*Rhot*((1/(3.3*0.735))-(1/(3.3*0.45))))/(Rhot*((3.3/(3.3*0.45))-1)-Rcold*((3.3/(3.3*0.735))-1))

Id: 2/7 Title: Solarconverter File: Solarconverter.sch Sheet: /Solarconverter/ TU Delft Drawn by Peter Verweij

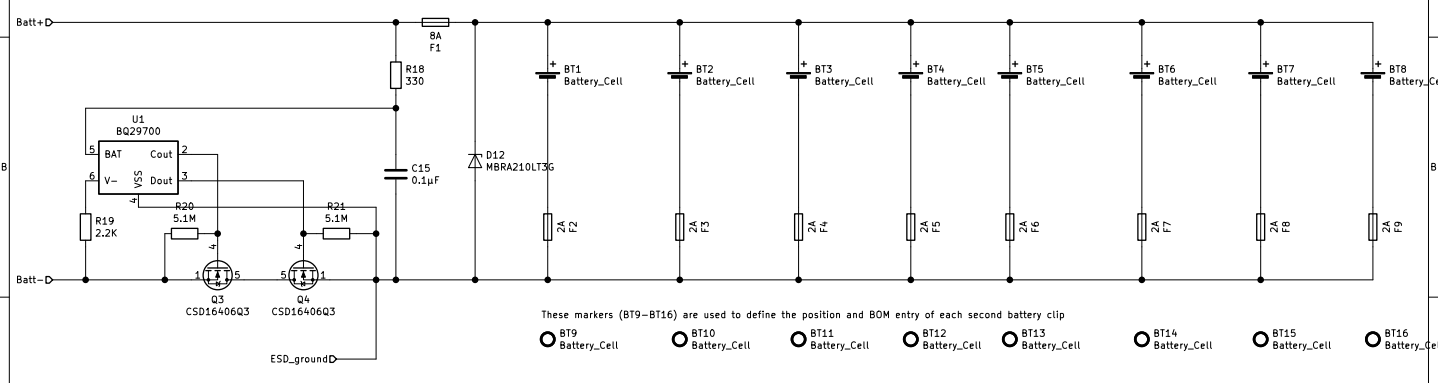
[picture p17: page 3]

Sheet: /Battery/ TU Delft Drawn by Peter Verweij

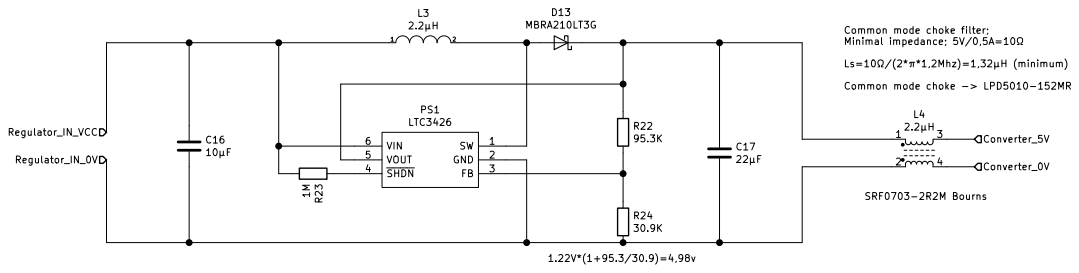
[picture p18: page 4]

SRF0703-2R2M Bourns Common mode choke filter; Minimal impedance; 5V/0,5A=10

Ls=10/(2**1,2Mhz)=1,32µH (minimum) Common mode choke -> LPD5010-152MR

Sheet: /VoltageRegulator/ TU Delft Drawn by Peter Verweij R23 1M

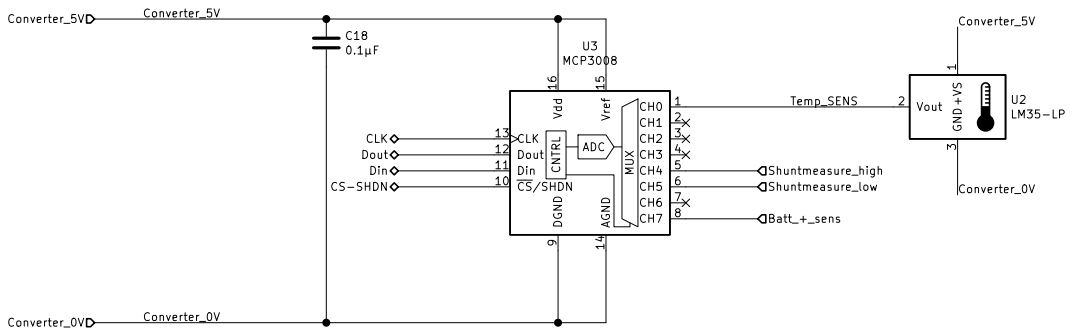
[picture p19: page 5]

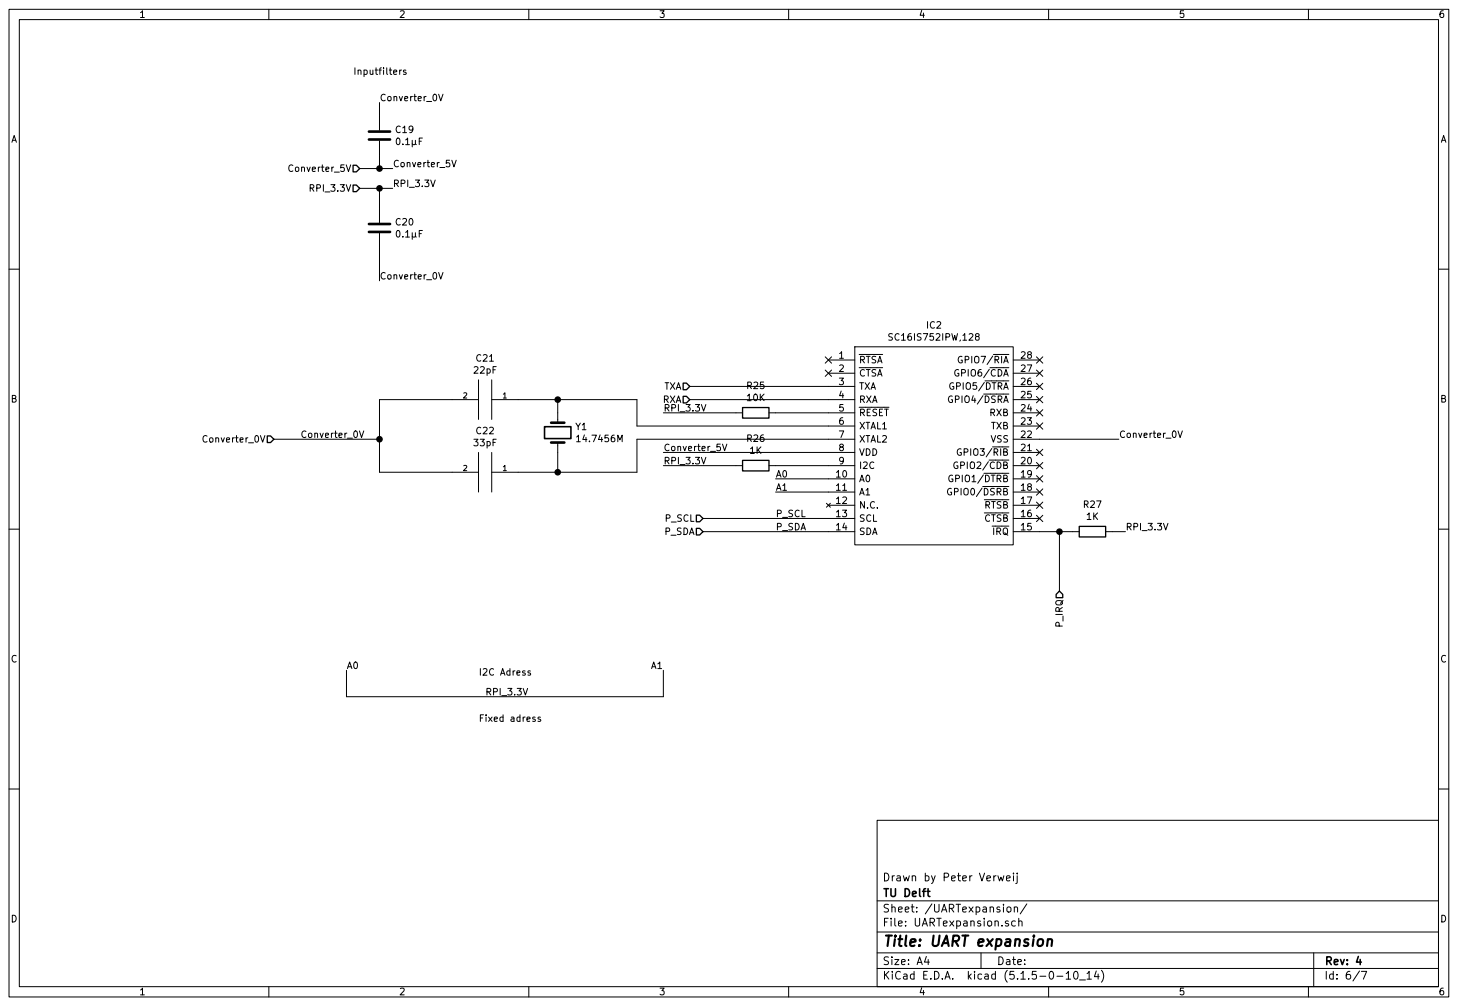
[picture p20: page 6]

Sheet: /UARTexpansion/ TU Delft Drawn by Peter Verweij

File: UARTexpansion.sch
Id: 6/7 Title: UART expansion

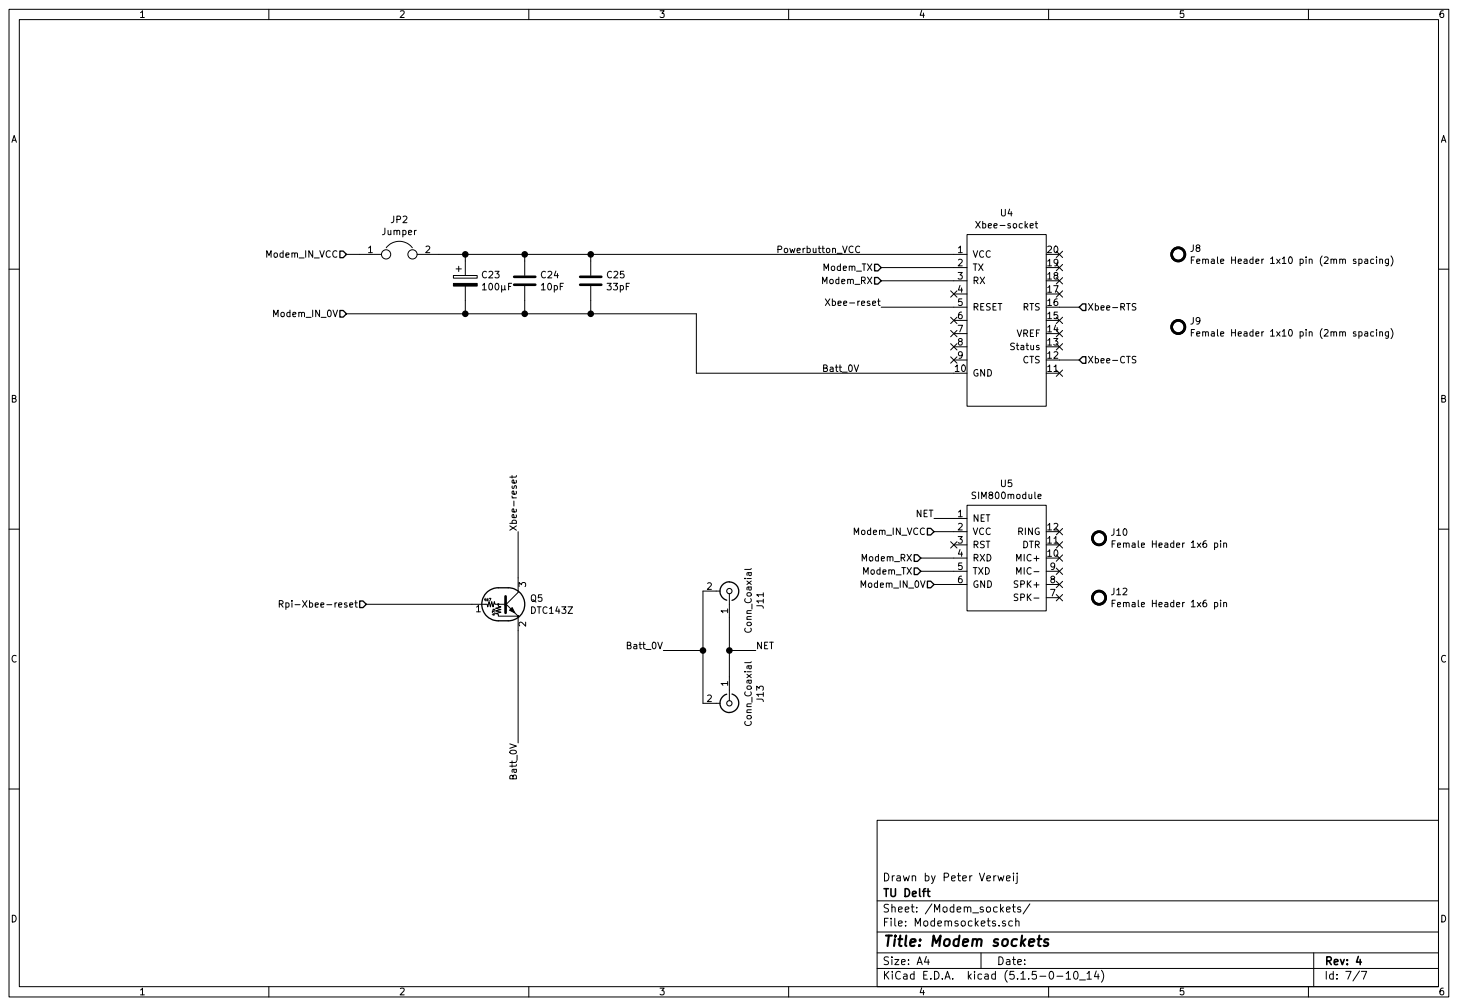
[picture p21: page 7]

J9 Female Header 1x10 pin (2mm spacing) J8 Female Header 1x10 pin (2mm spacing) J12Female Header 1x6 pin

2 3 Q5DTC143Z NET 1 MIC+ 10 DTR 11 RING 12 VCC 2 RST 3 RXD 4 TXD 5 GND 6 SPK- 7 SPK+ 8 MIC- 9 U5 SIM800module C25

File: Modemsockets.sch Sheet: /Modem_sockets/ TU Delft Drawn by Peter Verweij

Id: 7/7 Title: Modem sockets

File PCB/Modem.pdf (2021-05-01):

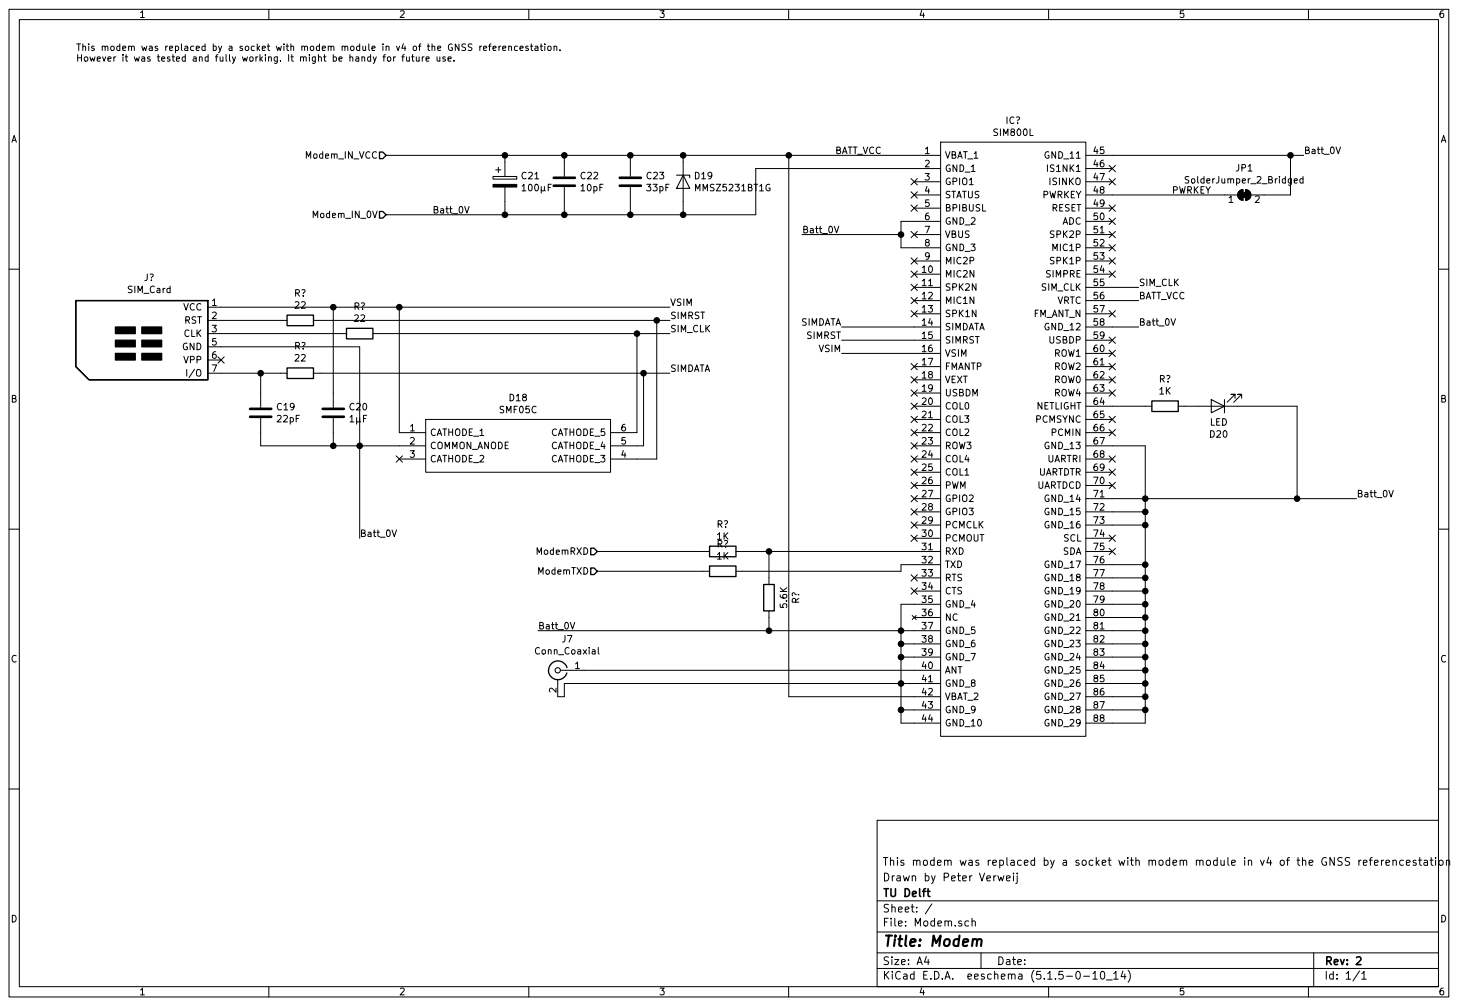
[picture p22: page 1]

This modem was replaced by a socket with modem module in v4 of the GNSS referencestation.
However it was tested and fully working. It might be handy for future use.

VCC 1 RST 2 CLK 3 GND 5 VPP 6

This modem was replaced by a socket with modem module in v4 of the GNSS referencestation
File: Modem.sch Sheet: / TU Delft Drawn by Peter Verweij

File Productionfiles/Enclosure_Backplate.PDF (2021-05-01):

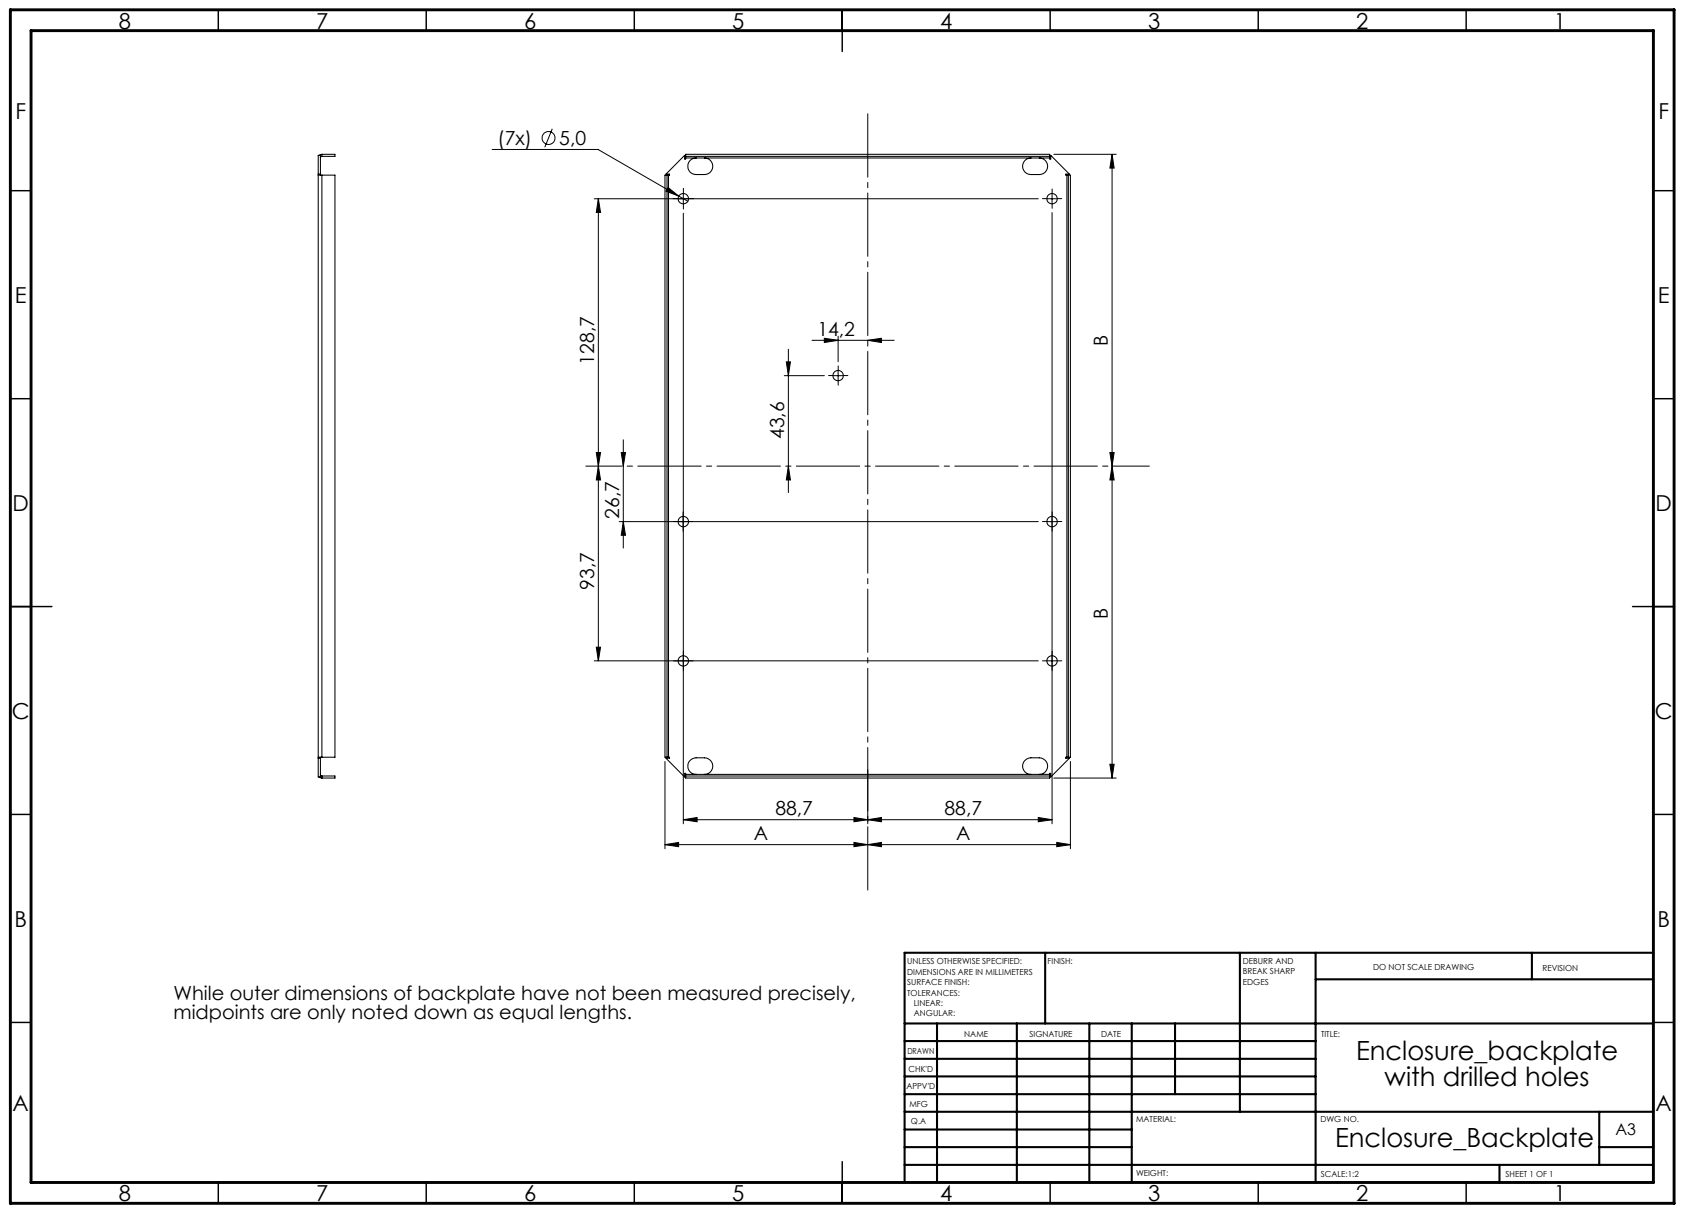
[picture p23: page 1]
FINISH:; DEBURR AND; BREAK SHARP; DO NOT SCALE DRAWING; REVISION; SCALE:1:2; SHEET 1 OF 1

UNLESS OTHERWISE SPECIFIED:
DIMENSIONS ARE IN MILLIMETERS
SURFACE FINISH:
TOLERANCES:
LINEAR:
ANGULAR:

While outer dimensions of backplate have not been measured precisely,
midpoints are only noted down as equal lengths.

NAME | SIGNATURE | DATE | | | | TITLE: Enclosure_backplate with drilled holes

DRAWN
CHK'D
APPV'D
MFG
Q.A | | | | MATERIAL: | DWG NO. Enclosure_Backplate | A3

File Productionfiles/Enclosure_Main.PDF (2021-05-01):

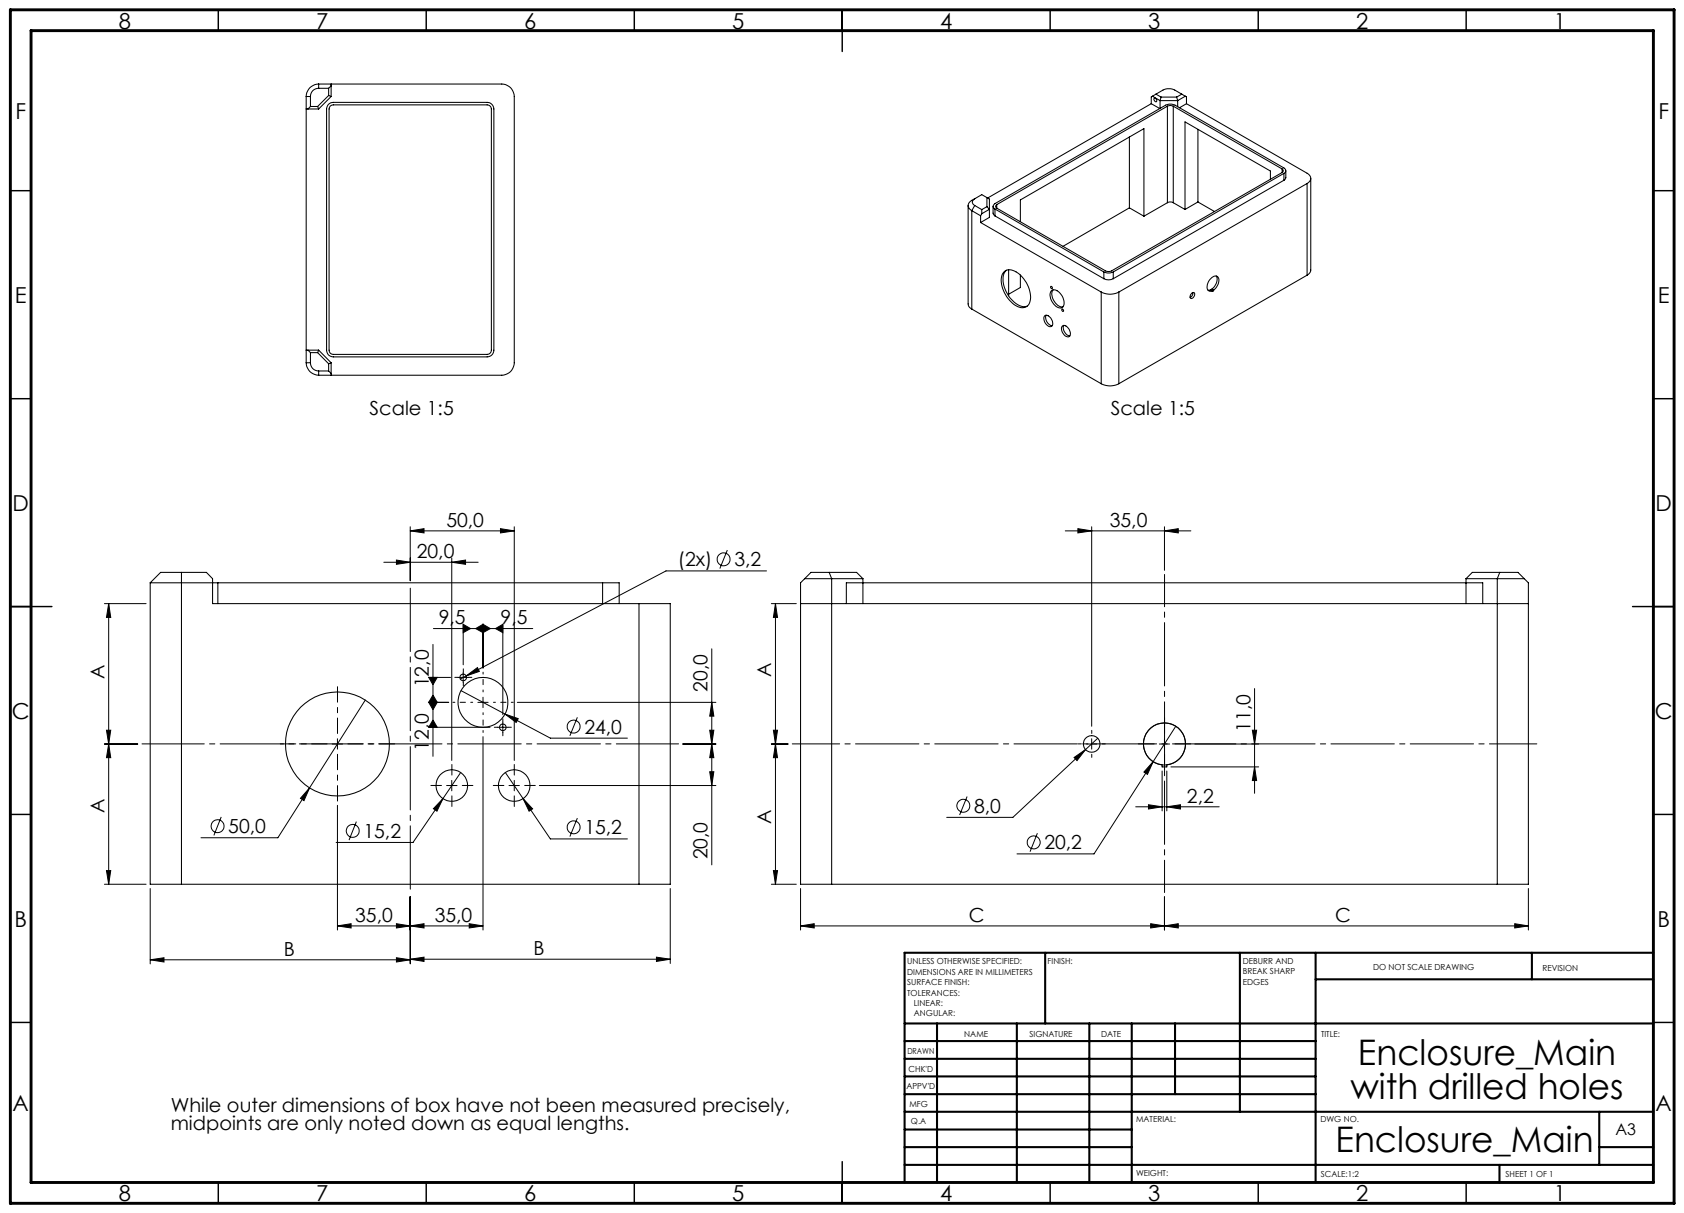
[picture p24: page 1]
Scale 1:5; FINISH:; DEBURR AND; BREAK SHARP; DO NOT SCALE DRAWING; REVISION; SCALE:1:2; SHEET 1 OF 1

UNLESS OTHERWISE SPECIFIED:
DIMENSIONS ARE IN MILLIMETERS
SURFACE FINISH:
TOLERANCES:
LINEAR:
ANGULAR:

NAME | SIGNATURE | DATE | | | | TITLE: Enclosure_Main with drilled holes

DRAWN
CHK'D
APPV'D
MFG
Q.A | | | | MATERIAL: | DWG NO. Enclosure_Main | A3

While outer dimensions of box have not been measured precisely,
midpoints are only noted down as equal lengths.

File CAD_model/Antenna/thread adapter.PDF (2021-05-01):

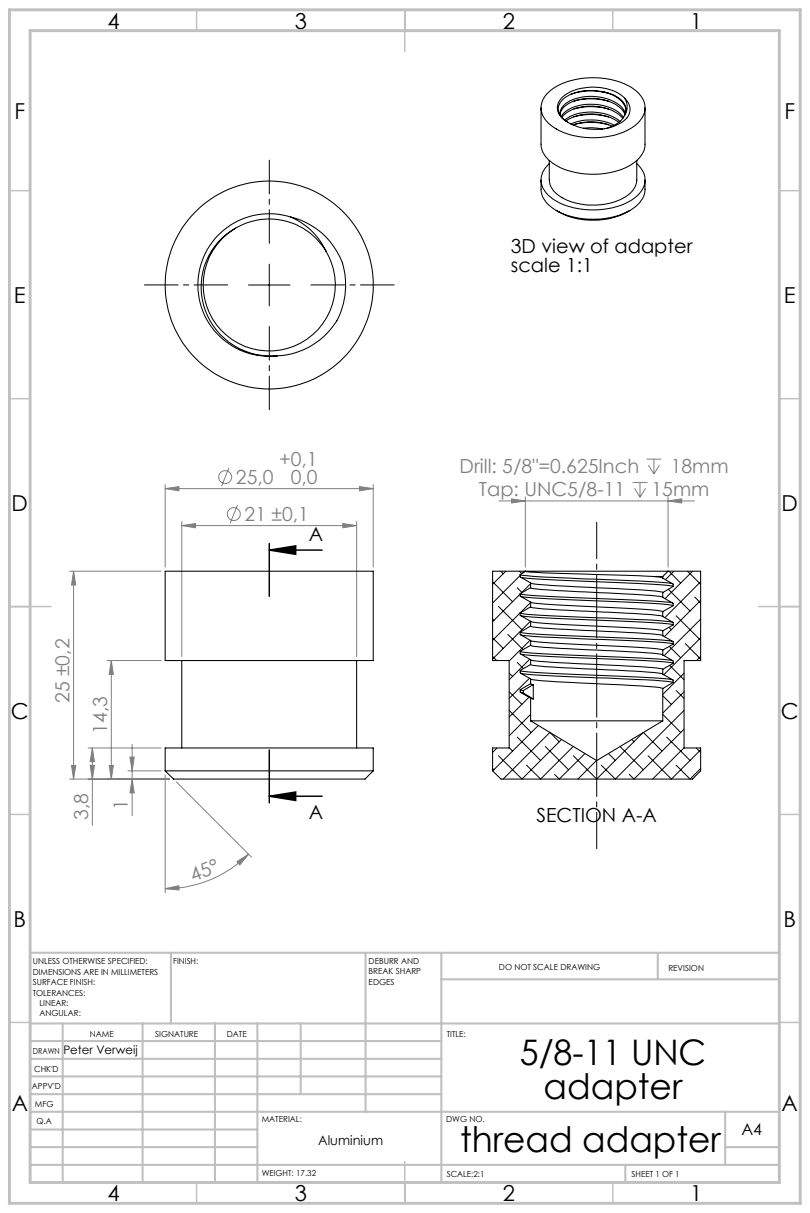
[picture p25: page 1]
Drill: 5/8"=0.625Inch 18mm Tap: UNC5/8-11 15mm; SECTION A-A; FINISH:; DEBURR AND; BREAK SHARP; DO NOT SCALE DRAWING; REVISION; SCALE:2:1; SHEET 1 OF 1; WEIGHT: 17.32

3D view of adapter
scale 1:1

UNLESS OTHERWISE SPECIFIED:
DIMENSIONS ARE IN MILLIMETERS
SURFACE FINISH:
TOLERANCES:
LINEAR:
ANGULAR:

NAME | SIGNATURE | DATE | | | | TITLE: 5/8-11 UNC adapter

DRAWN | Peter Verweij

CHK'D
APPV'D
MFG
Q.A | | | | MATERIAL: | DWG NO. thread adapter | A4 Aluminium

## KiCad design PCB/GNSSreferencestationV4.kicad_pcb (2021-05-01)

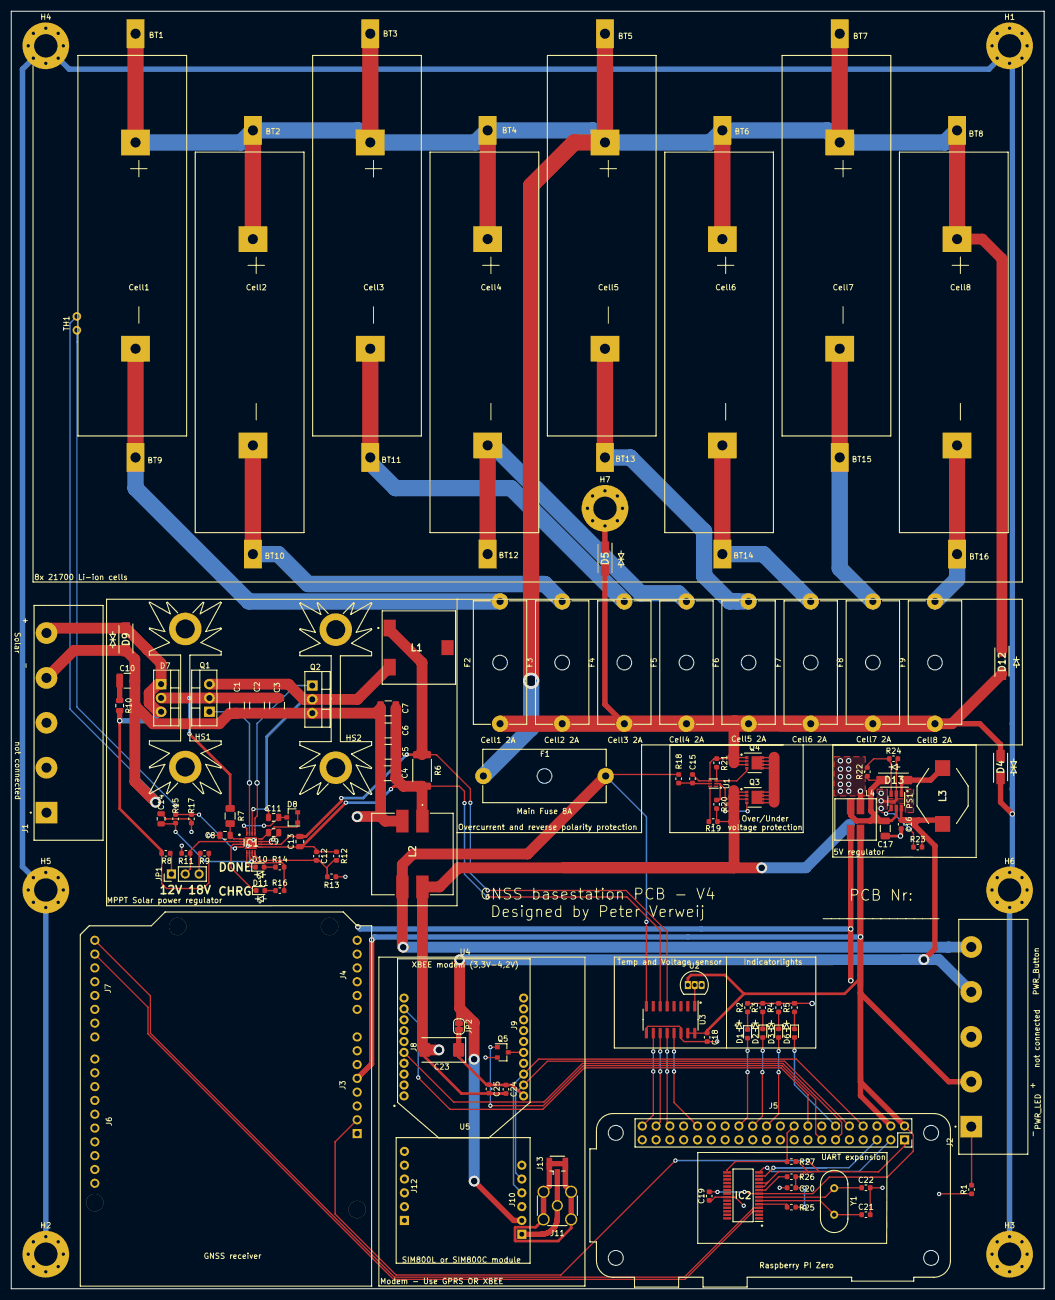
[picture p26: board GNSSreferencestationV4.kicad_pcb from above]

Board: 2 copper layers, 190.0 x 235.0 mm, 134 parts (0 on the bottom side), 80 nets.

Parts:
BT1, BT2, BT3, BT4, BT5, BT6, BT7, BT8: Battery_Cell; Keystone_246TR_20700
BT9, BT10, BT11, BT12, BT13, BT14, BT15, BT16: Battery_Cell; LocationMarker
C1, C2, C3, C4, C5, C6, C7: 10µ; C_1210_3225Metric
C8, C9, C14: 1µ; C_0805_2012Metric
C10: 2.2µ; C_1210_3225Metric
C11, C13: 0.1µ; C_0805_2012Metric
C12: 22p; C_0603_1608Metric
C15, C18, C19, C20: 0.1µF; C_0603_1608Metric
C16: 10µF; C_0603_1608Metric
C17: 22µF; C_1206_3216Metric
C21: 22pF; C_0603_1608Metric
C22, C25: 33pF; C_0603_1608Metric
C23: 100µF; CP_EIA-7343-30_AVX-N
C24: 10pF; C_0603_1608Metric
D1, D2, D3, D6, D10, D11: LED; LED_0603_1608Metric
D4, D5: SMA6T28CAY; DIOM5126X265N
D7: SBR10U40CT; TO-220-3_Vertical
D8: BAT54C; SOT-23
D9: SMA6T30CAY; DIOM5126X265N
D12, D13: MBRA210LT3G
F1: 8A; Fuseholder_Cylinder-5x20mm_Schurter_0031_8201_Horizontal_Op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
F2, F3, F4, F5, F6, F7, F8, F9: 2A; Fuseholder_Cylinder-5x20mm_Schurter_0031_8201_Horizontal_Op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
H1, H2, H3, H4, H5, H6, H7: Mounthole; MountingHole_4.3mm_M4_Pad_Via
HS1, HS2: Heatsink; Heatsink_Fischer_SK104-STCB_35x13mm__2xDrill3.5mm_ScrewM3
IC1: BQ24650RVAT; QFN50P350X350X100-17N-D
IC2: SC16IS752IPW,128; SOP65P640X110-28N
J1, J2: Conn_01x05_Female; TE_1-1437667-1
J3, J7: Female Header 1x8 pin; LocationMarker
J4, J10, J12: Female Header 1x6 pin; LocationMarker
J5: RPi_header; Raspberry_Pi_Zero_Socketed_THT_FaceDown_MountingHoles
J6: Female Header 1x10 pin; LocationMarker
J8, J9: Female Header 1x10 pin (2mm spacing); LocationMarker
J11: Conn_Coaxial; SMA_Amphenol_132134_Vertical
J13: Conn_Coaxial; U.FL_Hirose_U.FL-R-SMT-1_Vertical
JP1: Jumper_NC_Dual; PinHeader_1x03_P2.54mm_Vertical
JP2: Jumper; SolderJumper-2_P1.3mm_Bridged_RoundedPad1.0x1.5mm
L1: 15µH; SER1390-223MLB
L2: MSD1514-252MED; MSD1514
L3: 2.2µH; DO3316P102MLB
L4: 2.2µH; SRF0703-2R2M
PS1: LTC3426; TSOT-23-6
Q1, Q2: CSD18537NKCS; TO-220-3_Vertical
Q3, Q4: CSD16406Q3; VSON-8_3.3x3.3mm_P0.65mm_NexFET
Q5: DTC143Z; SOT-23
R1: 560; R_0603_1608Metric
R2, R3, R4, R5: 1.5K; R_0603_1608Metric
R6: 0.008; R_2512_6332Metric
R7: 10; R_1206_3216Metric
R8: 324K; R_0603_1608Metric
R9: 511K; R_0603_1608Metric
R10: 2; R_0805_2012Metric
R11: 36K; R_0603_1608Metric
R12: 340K; R_0603_1608Metric
R13: 348K; R_0603_1608Metric
R14, R16: 820; R_0603_1608Metric
R15: 3.48K; R_0603_1608Metric
R17: 14.7K; R_0603_1608Metric
R18: 330; R_0603_1608Metric
R19: 2.2K; R_0603_1608Metric
R20, R21: 5.1M; R_0603_1608Metric
R22: 95.3K; R_0603_1608Metric
R23: 1M; R_0603_1608Metric
R24: 30.9K; R_0603_1608Metric
R25: 10K; R_0603_1608Metric
R26, R27: 1K; R_0603_1608Metric
TH1: 10K; NTCLE100E3103HT1
U1: BQ29700; WSON-6_1.5x1.5mm_P0.5mm
U2: LM35-LP; TO-92L_Inline
U3: MCP3008; SOIC-16_3.9x9.9mm_P1.27mm
U4: Xbee-socket
U5: SIM800module
Y1: 14.7456M; Crystal_HC49-4H_Vertical
simpleRTK2B1: simpleRTK2B_header; simpleRTK2Bheaders_faceup

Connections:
/Batt_0V: C16.2, C17.2, C23.2, C24.2, C25.2, J11.2, J13.2, L2.4, L4.2, PS1.2, Q3.1, Q3.2, Q3.3, Q5.2, R19.2, R20.2, R24.2, U4.10, U5.6
/Batt_VCC: F1.1, J2.5, L2.3, R18.1, U3.8
/Converter_0V: C18.2, C19.1, C20.2, C21.2, C22.2, IC2.22, J5.6, J5.9, J5.14, J5.20, J5.25, J5.30, J5.34, J5.39, L4.4, R1.1, R2.2, R3.2, R4.2, R5.2, U2.3, U3.9, U3.14, simpleRTK2B1.GND1, simpleRTK2B1.GND2, simpleRTK2B1.GND3
/Converter_5V: C18.1, C19.2, IC2.8, J2.2, J5.2, J5.4, L4.3, U2.1, U3.15, U3.16, simpleRTK2B1.5V
/ESD_ground: C15.2, D4.2, D5.2, D12.2, F2.1, F3.1, F4.1, F5.1, F6.1, F7.1, F8.1, F9.1, Q4.1, Q4.2, Q4.3, R21.1, U1.4
/GNSS_RX: IC2.3, simpleRTK2B1.RX1
/GNSS_TX: IC2.4, simpleRTK2B1.TX1
/LED1: D6.2, J5.12
/LED2: D3.2, J5.22
/LED3: D2.2, J5.24
/LED4: D1.2, J5.26
/Modem_RX: J5.8, U4.3, U5.4
/Modem_TX: J5.10, U4.2, U5.5
/Modem_sockets/NET: J11.1, J13.1, U5.1
/Modem_sockets/Powerbutton_VCC: C23.1, C24.1, C25.1, JP2.2, U4.1
/Modem_sockets/Xbee-reset: Q5.3, U4.5
/P_CLK: J5.32, U3.13
/P_CS-SHDN: J5.40, U3.10
/P_Din: J5.38, U3.11
/P_Dout: J5.36, U3.12
/P_IRQ: IC2.15, J5.18, R27.2
/P_SCL: IC2.13, J5.5
/P_SDA: IC2.14, J5.3
/Powerbutton_OUT: C16.1, J2.4, JP2.1, L3.1, PS1.6, R23.2, U5.2
/RPI_3.3V: C20.1, IC2.10, IC2.11, J5.1, R25.2, R26.2, R27.1, simpleRTK2B1.IOREF
/Rpi_Xbee_Reset: J5.13, Q5.1
/Sensors/Temp_SENS: U2.2, U3.1
/Shuntmeasure_high: C13.2, IC1.10, L1.1, R6.2, U3.5
/Shuntmeasure_low: C4.2, C5.2, C6.2, C7.2, C12.1, C13.1, IC1.9, L2.1, R6.1, R12.1, U3.6
/Solarconverter/CHRG: D11.1, IC1.3
/Solarconverter/DONE: D10.1, IC1.5
/Solarconverter/Solar_IN_0V: C1.1, C2.1, C3.1, C4.1, C5.1, C6.1, C7.1, C8.1, C9.1, C10.2, C14.1, D9.2, IC1.11, IC1.17, J1.4, L2.2, Q2.3, R11.2, R13.2, R17.2, TH1.1
/Solarconverter/Solar_IN_VCC: D7.1, D7.3, D9.1, J1.5, R8.1, R9.1, R10.1
/Solarconverter/TERM_EN: C14.2, IC1.6, IC1.7, R14.2, R15.1, R16.2
/Solarconverter/TS: IC1.4, R15.2, R17.1, TH1.2
/Xbee-CTS: J5.16, U4.12
/Xbee-RTS: J5.11, U4.16
unnamed: BT1.1, BT2.1, BT3.1, BT4.1, BT5.1, BT6.1, BT7.1, BT8.1, D12.1, F1.2
unnamed: BT1.2, F2.2
unnamed: BT2.2, F3.2
unnamed: BT3.2, F4.2
unnamed: BT4.2, F5.2
unnamed: BT5.2, F6.2
unnamed: BT6.2, F7.2
unnamed: BT7.2, F8.2
unnamed: BT8.2, F9.2
unnamed: C1.2, C2.2, C3.2, D7.2, Q1.2, R7.1
unnamed: C8.2, IC1.1, R7.2
unnamed: C9.2, D8.1, D8.2, IC1.12
unnamed: C10.1, R10.2
unnamed: C11.1, IC1.14, L1.2, Q1.3, Q2.2
unnamed: C11.2, D8.3, IC1.16
unnamed: C12.2, IC1.8, R12.2, R13.1
unnamed: C15.1, R18.2, U1.5
unnamed: C17.1, D13.1, L4.1, PS1.5, R22.1
unnamed: C21.1, IC2.6, Y1.1
unnamed: C22.1, IC2.7, Y1.2
unnamed: D1.1, R2.1
unnamed: D2.1, R3.1
unnamed: D3.1, R4.1
unnamed: D4.1, H1.1, H2.1, H3.1, H4.1, H5.1, H6.1
unnamed: D5.1, H7.1
unnamed: D6.1, R5.1
unnamed: D10.2, R14.1
unnamed: D11.2, R16.1
unnamed: D13.2, L3.2, PS1.1
unnamed: IC1.2, JP1.2, R11.1
unnamed: IC1.13, Q2.1
unnamed: IC1.15, Q1.1
unnamed: IC2.5, R25.1
unnamed: IC2.9, R26.1
unnamed: J2.1, R1.2
unnamed: JP1.1, R8.2
unnamed: JP1.3, R9.2
unnamed: PS1.3, R22.2, R24.1
unnamed: PS1.4, R23.1
unnamed: Q3.4, R20.1, U1.2
unnamed: Q3.5, Q4.5
unnamed: Q4.4, R21.2, U1.3
unnamed: R19.1, U1.6

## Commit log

2021-03-31 Create Manual - printable.pdf
2021-05-01 Initial upload
    [Antenna.Antennatop.Assembly.SLDASM, Antenna.Pole-1000mmx25mm.SLDPRT, Antennatop.Base-hole25,5mm.STL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]
